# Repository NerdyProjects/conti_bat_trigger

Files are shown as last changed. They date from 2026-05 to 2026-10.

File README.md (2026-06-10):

## Contiakku Triggerplatine

Die Conti-Akkus aus dem Finger-Forum liegen immer noch rum, eine Platine muss her, damit es einfach wird.

[Foren Thread: Conti-Akku, Technikfaden](https://www.fingers-welt.de/phpBB/viewtopic.php?t=19876)

**Status: Untested**

### Funktionalität
* 4,8mm Flachstecker auf der Platine, die direkt auf den Akkustecker passen (zusätzliches Gehäuse empfehlenswert, da ohne kein Verpolschutz!)
* ESP32-C3 Supermini als Basis: Billig, einfach, mit CAN, USB, Wlan.
* Versorgung vom Akkupack oder Charger
* Trigger des Wakeups auf 12V oder 0V
* Trigger des Wakeups auf 12V für Akkus im Deepsleep, wenn Ladegerät angeschlossen
* Wachhalten per CAN

### Timeline
* Mitte Mai: PCB Bestellung
* Bis Ende Mai: Erste Tests geplant

## Errata
### HW v1 (Prod. 2026-05-06)
 * Fehlender Widerstand am Wakeup-Pullup. Wenn Pullup und Pulldown gleichzeitig aktiviert werden würden, kommt es zum Kurzschluss. Abhilfe: Leiterbahn zwischen D13 und R13 durchtrennen, einen Widerstand 1-5k darüber löten. Der passt gut auf die Pads mit drauf. Alternativ den Trace zwischen R15 und D13 (der von Q3 zu D3 geht) durchtrennen, etwas Lötstopp wegkratzen und dort die 1-3k einlöten.
 * Spannungsregler ist immer an - der Conti-Akku gibt auch im Aus-Zustand etwas Spannung am Batterie-Pin aus. Das reicht um die Platine "halb" zu starten - der ESP hat keinen Strom, aber die LED leuchtet. Führt zu höherem Ruhestrom bei gesteckter Platine.

 ### HW v2 (Prod. 2025-05-29)
 * Spannungsregler Enable ist auf etwa 7,5V Einschaltschwelle konfiguriert, allerdings gibt der Akku eine Leerlaufspannung von knapp 16V aus im abgeschalteten Zustand. Leider startet der Spannungsregler dann immernoch, die Platine braucht wenige mA Strom. Damit die Platine sowohl Lade-Wakeup (Versorgung per BAT+) und Entladewakeup (Versorgung über 12Vout) kann, gibt es hier leider keine sinnvolle Einschaltschwelle, ich habe keine Lösung für das Problem.

 ### Aufbau
 #### Charge Only
 * Nur als Ladewachhalter, lädt ?max. 8 Stunden oder bis Akku voll; jedenfalls länger als 1 Stunde?.
 * Achtung: Der Akku stoppt den Ladevorgang scheinbar nicht selbstständig! Überladegefahr!
 
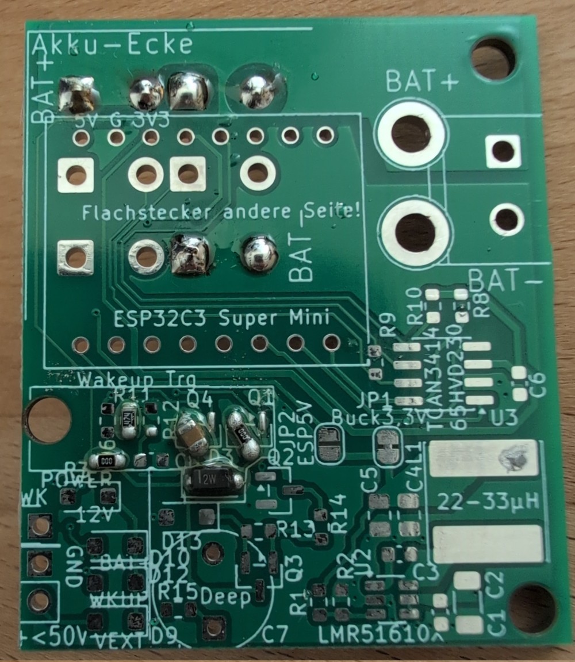
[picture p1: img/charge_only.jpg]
 

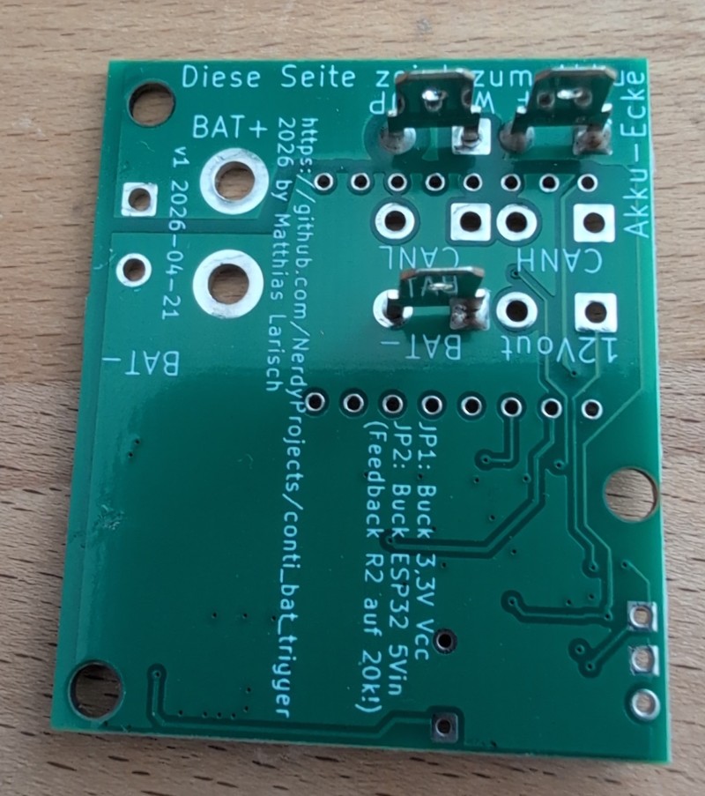
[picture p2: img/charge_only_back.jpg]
 

 Von links nach rechts:
 * R3: 0 Ohm - 1 kOhm
 * R11: 470 kOhm zum Entladen vom Wakeup-Kurzschluss-Trigger-Kondensator
 * Q4 diagonal: 1-10µF Wakeup-Kurzschluss-Trigger-Kondensator
 * D3: 12V Zenerdiode, Strich nach links (Durchlassrichtung rechts nach links)
 * Q1: Brücke von Pin 2 nach 3

 #### ESP Bestückung

 Ganz wichtig: Reihenfolge beachten, sonst kommt man nicht mehr an die Pads dran.

 1. Stiftleisten auf Platine löten - ggf. zum richtigen Abstand halten den ESP bzw. die Adapterplatine schon oben auflegen
 2. Flachstecker bestücken (siehe unten)
 3. Sofern der Display-Adapter zum Einsatz kommt, nun die oberen Stiftleisten hier anlöten - ovale Pads. Achtung: Die obere Reihe kollidiert sehr schnell mit den Flachsteckern, kurze Seite der Stiftleiste nach unten bzw. nachkürzen!
 4. Display Adapter auf Platine löten, dabei nochmal genau mit allen Abständen schauen, ggf. etwas hoch stehen lassen, wenn Flachstecker zu weit hochschauen.
 5. ESP auf Displayadapter bzw. Platine löten - genau darauf achten, dass unterhalb kein Kurzschluss entsteht - ggf. etwas mehr Abstand lassen.

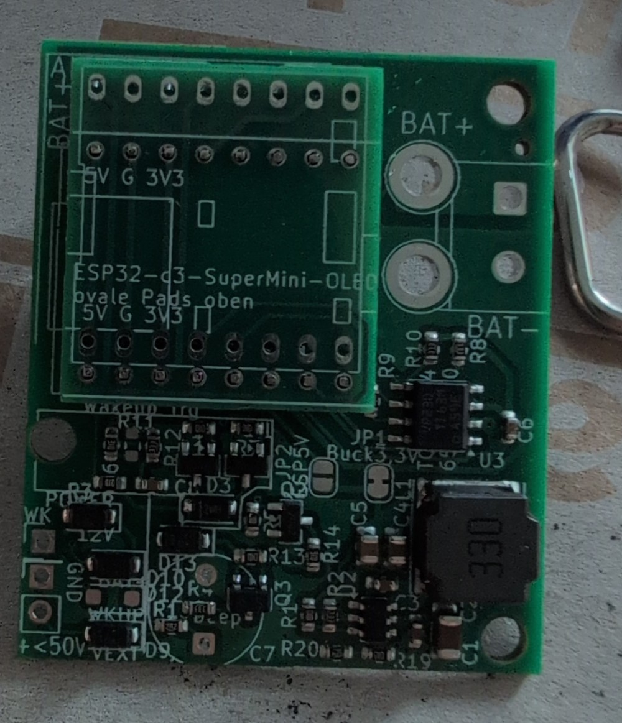
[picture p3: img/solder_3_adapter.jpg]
 

So sieht das aus, wenn man in der falschen Reihenfolge lötet. Mit etwas mehr Abstand noch rettbar :-)

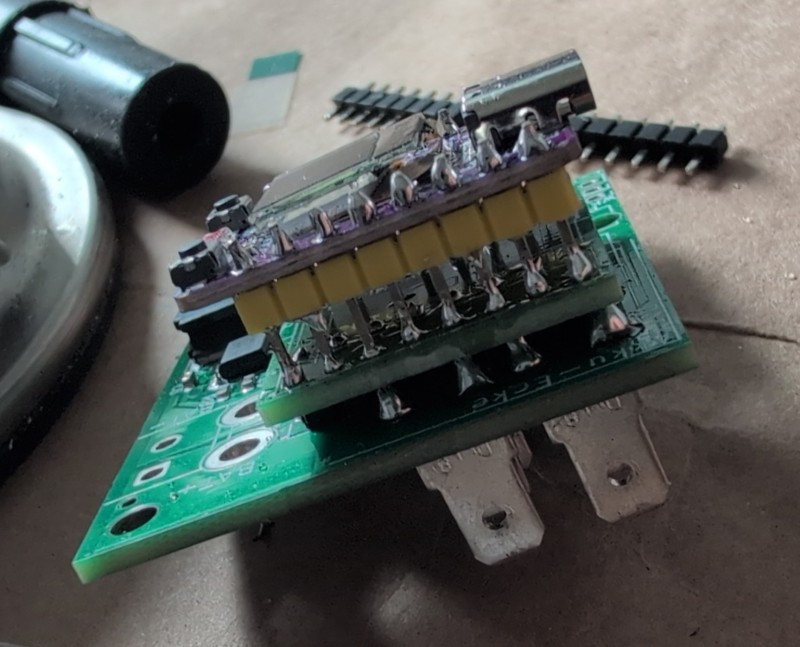
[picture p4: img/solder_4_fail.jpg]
 

Und fertig, mit Oled und der ersten Software:

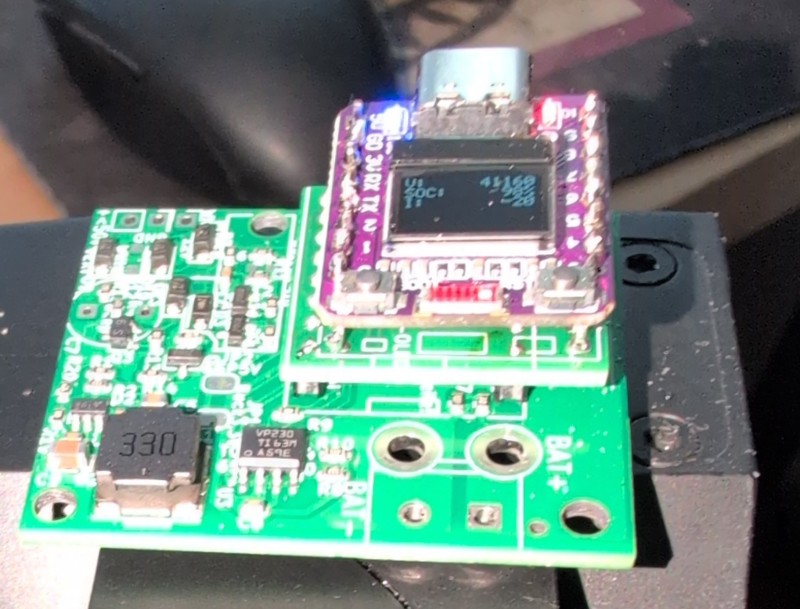
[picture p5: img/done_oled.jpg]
 

 #### Flachstecker-Bestückung

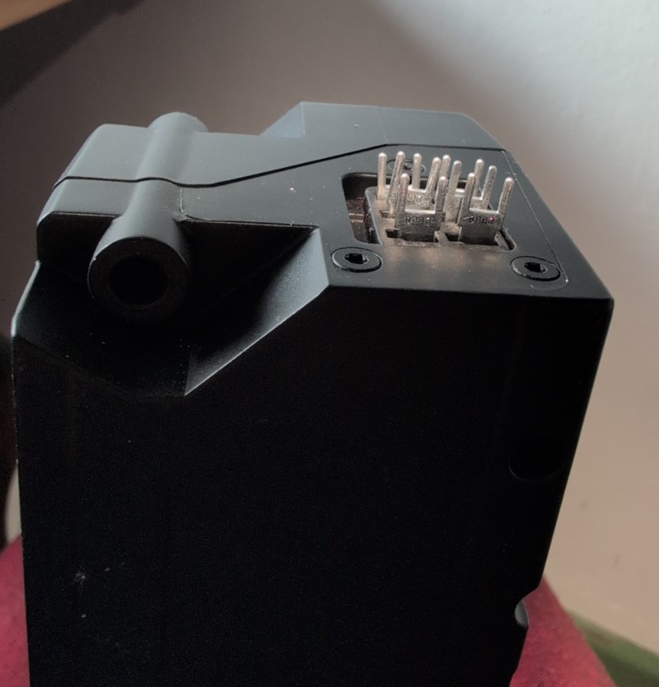
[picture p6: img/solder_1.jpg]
 

 * Flachstecker am besten in einen Conti-Akku stecken. Soweit bekannt, passiert hier bei Kurzschlüssen nichts.

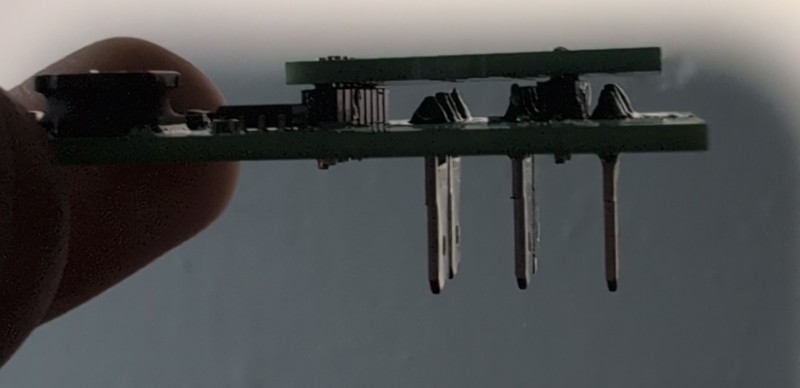
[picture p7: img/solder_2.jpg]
 

 * Beim Anlöten der Platine darauf achten, die Flachstecker nicht ganz durchzustecken, alternativ muss später oben Abstand gehalten werden. Sprich: Insgesamt darauf achten, dass die Flachstecker am Ende keinen Kurzschluss mit der Platine darüber machen.

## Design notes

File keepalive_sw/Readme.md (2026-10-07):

### Keepalive Software

Diese Software kann mit der Hardware den Akku so steuern, dass er im Lade- (Wakeup auf 12V) oder Entlade-(CAN Nachrichten regelmäßig senden) Modus aktiv bleibt.

Hardware: ESP32 C3 SuperMini oder die OLED Variante - in der sdkconfig bzw. per menuconfig gibt es dafür den Abschnitt:
```
#
# Hardware Variant
#
# CONFIG_HW_VARIANT_SUPERMINI is not set
CONFIG_HW_VARIANT_OLED=y
# end of Hardware Variant
```

Die SW macht einen WiFi-AP mit einer Debug-Webschnittstelle auf. Die Zugangsdaten können unter wifi_ap.h konfiguriert werden.

### Display-Akku aktualisieren (ein Befehl)

```bash
python3 tools/stm_display_fw.py flash data/stm32f105_bms_control.bin
```

Wartet auf das Gerät, holt die laufende Applikation per Software-Reset
automatisch in den Bootloader, flasht die Applikationsregion und wartet dann
20 s auf die Applikation. Diese startet **nicht** von selbst: der Abschluss
`0x3E 0x80` loest ohne weitere Rahmen gar keinen Reset aus und ein
Software-Reset fuehrt per Firmware-Logik wieder in den Bootloader — daher nach
dem Flashen Akku/Display kurz stromlos machen (Stecker ab- und wieder
anstecken, Pin-Reset). Nachgewiesen mit `tools/emu.py finishtimer` bzw.
`bootdecision`, Details in `tools/PROTOCOL.md` §9.7.
Optionen: `--wait <Sekunden>` (Standard 120), `--region app|all`,
`--no-reset` (nicht selbst springen), `-q` (weniger Ausgabe).

Voraussetzungen: Python 3 mit `hidapi`, Schreibrechte auf `/dev/hidraw*`
(udev-Regel: `tools/99-continental-ebike.rules`), Akku/Display eingeschaltet.

Hinweise für den Fall, dass es nicht klappt:

* `python3 tools/stm_display_fw.py info` — ist Gerät/Bootloader sichtbar?
* `python3 tools/stm_display_fw.py crc` — stimmt die Applikations-CRC?
  (zerstörungsfrei; Status `0` = stimmt, `1` = verändert/leer)
* Auch wenn das Flashen abbricht, bleibt das Gerät benutzbar: der Bootloader
  liegt unterhalb `0x08008000` und ist **nicht** beschreibbar; das Gerät bleibt
  im Bootloader-Modus erreichbar und kann einfach erneut geflasht werden.
* Details zur Analyse: `data/Flash_WRP_Befund.md`, `tools/PROTOCOL.md`.

### Display-Akku per BLE auslesen (POC)

Das Display (BLE-Name `CEBS`) meldet die BMS-Telemetrie. Kleines POC-Werkzeug
`tools/cebs_ble.py` (Voraussetzung: `pip install bleak`):

```bash
python3 tools/cebs_ble.py              # sucht 'CEBS', verbindet, gibt 1x/s aus
python3 tools/cebs_ble.py --json       # eine JSON-Zeile je Messwert
python3 tools/cebs_ble.py --list       # GATT-Baum anzeigen
```

Erster Continental-Vendor-Service (`00000a00-…`) / erste Charakteristik
(`00000a01-…`) = Verkettung der BMS-CAN-Rahmen `0x404`+`0x405`+`0x406`:
Byte 1–2 = Strom (`int16` LE, mA), Byte 3–4 = Spannung (`uint16` LE, mV),
Byte 5 = SOC (%), Byte 6 = SOH (%, Vermutung), Byte 7–8 = RemainingCapacity
(mAh), Byte 9–10 = FullChargeCapacity (mAh), Byte 15–16 = **Durchschnittsstrom**
(`int16` LE, mA). Details siehe Modul-Docstring.

Zwei Ströme: `0x404` liefert den schnell nachgeführten Wert, `0x406` (Byte
15–16) einen trägen Durchschnitt (Zeitkonstante ca. 10–20 s, Auflösung
10 mA). Nachgewiesen mit einem ~100-mA-Lastsprung: der erste Wert springt
sofort, der zweite läuft exponentiell nach.

Für eigene Messreihen (z. B. Sprungantworten) gibt es
`tools/cebs_ble_trace.py` – liest mit einstellbarer Rate und schreibt jede
Änderung mit Zeitstempel in eine CSV:

```bash
.venv/bin/python tools/cebs_ble_trace.py --seconds 120 --csv trace.csv
```

Hinweis: Die Charakteristik ist **read-only** (keine Notifications, BlueZ
meldet „Operation is not supported"). Werte müssen also gelesen werden; das
Display aktualisiert sie ca. 1x/s. Nur **eine** BLE-Zentrale gleichzeitig:
Solange ein Rechner verbunden ist, sendet das Display nicht mehr und ist für
andere (z. B. die Handy-App) unsichtbar – Verbindung vorher trennen
(`bluetoothctl disconnect <adresse>`).

### Akku-Check als Android-App

Dieselben Daten als Handy-App für einen schnellen Akkucheck:
`android/CebsBatteryCheck`. Verbindet beim Start automatisch (Scan nach Name
`CEBS`), zeigt Ladezustand/Spannung/Strom/Leistung/Kapazität groß an und
liest ausschließlich – es wird nie etwas geschrieben.

```bash
cd android/CebsBatteryCheck
./gradlew :app:assembleDebug     # oder :app:installDebug mit angeschlossenem Gerät
```

Details: `android/CebsBatteryCheck/README.md`.

### Display-Akku als CAN-Interface nutzen (USB-HID)

Die Display-App ist über ihre normale USB-HID-Schnittstelle
(`Continental eBike System`) auch eine kleine **CAN-Bruecke**: Frames senden
und die von der App gemeldeten Frames mitlesen. Ein Frame ist genau ein
64-Byte-HID-Report; Details (Adressen, Filter, Sequenz) stehen in
`tools/PROTOCOL.md` §10.

```bash
python3 tools/can_hid.py info
python3 tools/can_hid.py send 0x201 01 02 03 04        # einen CAN-Frame senden
python3 tools/can_hid.py send 0x201 01 02 --repeat 10  # zyklisch senden
python3 tools/can_hid.py batch --frame "0x201 01 02" --frame "0x202 03 04"
python3 tools/can_hid.py listen 5                      # CAN-Frames mitlesen
```

* **Senden** geht fuer jede 11-Bit-ID **ausser `0x550`** (die Firmware
  filtert an `0x0801D522` fehlerhaft); Nutzlast <= 8 Byte. `0x550` ist der
  reine App-Nachrichtenkanal.
* **Mitlesen** liefert bei Original-Firmware nur die fest verdrahteten IDs
  `0x422 0x425 0x101 0x331 0x668`. Fuer **generischen Empfang** (jedes Frame)
  die Firmware mit dem optionalen Patch C1 bauen und flashen:
  ```bash
  python3 tools/patch_bms.py --can-sniffer        # P1..P7 + C1, CRC neu
  python3 tools/stm_display_fw.py flash data/stm32f105_bms_control.bin
  ```
  C1 haelt den App-Handler-Dispatch erhalten (Details: `tools/PROTOCOL.md` §11).
* Offline pruefen (ohne Hardware): `python3 tools/emu.py canbridge` und
  `python3 tools/can_hid.py selftest`.

### Flash-Inhalt prüfen (verify) und auslesen (dump)

```bash
python3 tools/stm_display_fw.py verify data/stm32f105_bms_control.bin
python3 tools/stm_display_fw.py dump rec
# exakter Beweis -- SCHREIBT 2 KiB in den Flash (verlangt -y):
python3 tools/stm_display_fw.py verify data/stm32f105_bms_control.bin --deep -y
```

* `verify` (**nur lesend**) prüft erst die Datei (CRC-Wort gegen berechnete
  CRC) und dann den Flash über `0x31/0x10202`. Der Bootloader meldet nur ein
  Statusbit (`0` = CRC stimmt, `1` = stimmt nicht). Das belegt die
  **Selbstkonsistenz** des Bereichs: Inhalt und gespeichertes CRC-Wort passen
  zueinander. Ein *anderes*, in sich stimmiges Image würde hier ebenfalls „0"
  ergeben.
* `verify --deep -y` beweist dagegen, dass es **genau dieses** Image ist:
  die letzte 2-KiB-Seite `0x0803F800` (enthält das CRC-Wort) wird gelöscht und
  aus dem Image neu geschrieben, danach wird die CRC abgefragt. Ergebnis `0`
  heißt: der gesamte Applikationsbereich entspricht dem Image.
  **Achtung, das schreibt**: der alte Inhalt dieser Seite ist nicht lesbar
  (der Bootloader kann nur `0x08007800` lesen) und damit auch nicht sicherbar.
  Ohne `-y` verweigert das Tool den Befehl und erklärt die Folgen. Bei einem
  Abbruch nach dem Löschen startet die Applikation nicht mehr — das Gerät
  bleibt dann im Bootloader und wird einfach neu geflasht (der Bootloader
  selbst liegt unter `0x08008000` und ist gesperrt).
* `dump rec` liest den 6-Byte-Record bei `0x08007800` (Kommando `0x22`
  mit Magic `0xF15B`, auf USB kommen 6 Byte zurück; im Original leer).
* **Einen kompletten Dump gibt es nicht**: der Bootloader hat keinen
  Lese-Befehl (10 Kommandos, alle schreiben/steuern; Antworten tragen nur
  Status). Die Record-Seite bei `0x08007800` ist die einzige auslesbare
  Flash-Adresse. Inhaltskontrolle erfolgt daher über `verify`.

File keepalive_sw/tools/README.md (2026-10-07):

# CEBS / Continental Display – BMS-Patch (STM32F105)

Stand: 2026-10-04

Werkzeugpaket zum **Patchen und Flashen** der Display-Firmware über den
USB-HID-Bootloader. Kein SWD/JTAG, kein Löten, kein Windows-Originaltool.

Ergebnis des Patches: Das Display sendet die CAN-Botschaft `0x555`
(BMS-Freigabe) genau dann mit **1**, wenn es läuft – dauerhaft, auch ohne
`0x201`-Keepalive. Details: `docs/BMS_Patch.md`.

## Inhalt

| Pfad | Inhalt |
|---|---|
| `firmware/stm32f105_conti.{bin,hex}` | **Original-Firmware** (unverändert, Ausgangspunkt) |
| `tools/patch_bms.py` | Patches P1…P7 anwenden + Applikations-CRC neu rechnen |
| `tools/o2_cave.s`, `tools/o2_cave.ld` | Assemblerquelle/Platzierung des O2-Patches (Code-Cave) |
| `tools/stm_display_fw.py` | Flash-Werkzeug (USB-HID): flashen, prüfen, diagnostizieren |
| `tools/emu.py` | Emulator (Unicorn): Patch- und Flash-Weg **ohne Hardware** nachvollziehen |
| `tools/cebs_ble.py` | POC: BMS-Telemetrie (Strom/Spannung/SOC/Kapazität) per BLE auslesen |
| `tools/can_hid.py` | CAN über USB-HID der App: Frames senden und mitlesen (siehe `PROTOCOL.md` §10) |
| `tools/patch_bms.py --can-sniffer` | optionaler Patch C1: **generischer** CAN-Empfang, alle Frames ans HID (`PROTOCOL.md` §11) |
| `tools/PROTOCOL.md` | Protokolldokumentation (Bootloader, Kommandos, Fallstricke) |
| `tools/99-continental-ebike.rules` | udev-Regel für USB-Zugriff ohne `root` (Linux) |
| `docs/` | Hintergrund: Patchliste, Firmware-Update-Analyse |
| `patch.sh`, `flash.sh` | Kurzbefehle für die beiden Schritte |
| `esp32/keepalive_sw_supermini.bin`, `esp32/keepalive_sw_oled.bin` | ESP32-C3 App-Images je Hardware-Variante (Web-OTA) |
| `esp32/bootloader.bin`, `esp32/partition-table.bin`, `esp32/ota_data_initial.bin` | ESP32-C3 Bestandteile für den USB-Flash |
| `flash_ota.py` | ESP32 per WiFi/Web-OTA aktualisieren |
| `flash_esp32_usb.sh` | ESP32 per USB flashen (esptool) |
| `idf_env.sh` | Hilfsbibliothek: ESP-IDF-Umgebung finden (von den ESP-Skripten genutzt) |

## 0. Kurzfassung - vorgefertigtes Teil flashen
```bash
sudo apt install python3-venv
python3 -m venv .venv
source .venv/bin/activate
pip install -r requirements.txt
sudo sh tools/install-udev.sh        # kopiert die udev-Regel und lädt sie neu
# Akku per Micro-USB anstecken. Achtung: danach muss der nächste Befehl innerhalb von 5 Sekunden ausgeführt werden, da
# der Akku sich sonst resettet. Passiert das, Kabel für 10 Sekunden abziehen & wieder anstecken.
# Schauen ob alles geht:
python3 tools/stm_display_fw.py info
# Flashen: (ggf. wieder Akku neu anstecken)
python3 tools/stm_display_fw.py flash firmware/stm32f105_bms_control.bin
```

USB Kabel ab, Akku sollte dann über langen (>2s aber <30s) Tastendruck ein- und auszuschalten sein. Er bleibt dauerhaft an, wenn er nicht manuell ausgeschaltet wird.

## 1. Einrichten (einmalig)

```bash
sudo apt install python3-venv gcc-arm-none-eabi binutils-arm-none-eabi

cd cebs_display_bms_patch
python3 -m venv .venv
source .venv/bin/activate
pip install -r requirements.txt
```

**USB-Zugriff ohne `root`** (Linux, einmalig):

```bash
sudo sh tools/install-udev.sh        # kopiert die udev-Regel und lädt sie neu
# danach das Display einmal ab- und wieder anstecken
```

Kontrolle, ob das Gerät sichtbar ist:

```bash
python3 tools/stm_display_fw.py info
```

## 2. Firmware patchen

```bash
./patch.sh
```

Das entspricht:

```bash
python3 tools/patch_bms.py -i firmware/stm32f105_conti.hex \
                           -o firmware/stm32f105_bms_control
```

Ergebnis: `firmware/stm32f105_bms_control.bin` und `.hex`. Die Ausgabe listet
für jeden Patch `angewendet` (P5 ist durch P7 abgelöst und wird automatisch
ausgelassen) und zeigt danach die neue Applikations-CRC.

* nur ansehen, nichts schreiben: `python3 tools/patch_bms.py --list`
* Cave-Code anzeigen (assembliert + Disassembly): `python3 tools/patch_bms.py --print-o2`

## 3. Flashen

1. **USB-Kabel anstecken**, Akku/Display versorgt. Die Anwendung darf laufen –
   das Werkzeug holt sie selbst per Software-Reset in den Bootloader.
2. Flashen:

```bash
./flash.sh
```

Das entspricht:

```bash
python3 tools/stm_display_fw.py flash firmware/stm32f105_bms_control.bin
```

Ablauf (dauert etwa eine Minute):

```
[flash] Applikation laeuft -> Software-Reset in den Bootloader ...
[flash] Bootloader bereit: /dev/hidrawX
[upload] loesche 0x08008000..0x0803ffff   (112 Seiten, Status 0, ~7 s)
[stream] 229376 Bytes = 1+4095 Rahmen a 56 Byte        (Fortschritt, ~20 s)
[stream] Endquittung 0x76 -- Schreibzeiger steht exakt auf 0x08040000.
[upload] App-CRC stimmt (Status 0) -- Bereich vollstaendig und konsistent.
[upload] Sitzung beendet (0x3E 0x80) -- die Applikation startet davon nicht:
         0x3E 0x80 ist KEIN Reset, sondern armt nur einen Zaehler (5000, der
         eigene Rahmen zaehlt schon mit -> 4999), den der Bootloader um eins je
         WEITEREM empfangenen USB-Rahmen verringert (kein Zeitgeber). Danach
         senden wir nichts mehr -- es passiert also nichts, auch kein Reset in
         "dmesg" (tools/emu.py finishtimer). Und selbst ein Reset dort waere
         ein Software-Reset und fuehrt per Firmware-Logik wieder in den
         Bootloader (RCC_CSR.SFTRSTF, tools/emu.py bootdecision).
         -> Akku/Display kurz stromlos machen (Stecker ziehen und wieder
            anstecken) -- nur dieser Pin-Reset startet die Applikation.
[flash] Flash fertig: Image geschrieben und App-CRC (Status 0) bestaetigt.
[flash] Kein Auto-Reset in die Applikation (siehe Reset-Meldung oben, PROTOCOL.md 9.7).
[flash] -> Jetzt Akku/Display kurz stromlos machen (USB-Stecker abziehen und
[flash]    wieder anstecken). Ich warte bis zu 20 s darauf ...
[flash] fertig -- Applikation laeuft.
```

**Wichtig – Power-Cycle nach dem Flashen:** Nach dem Upload macht der
Bootloader von sich aus **keinen** Reset (auch nichts in `dmesg`): `0x3E 0x80`
armt nur einen Zähler, der um *eins je weiterem empfangenen USB-Rahmen* sinkt –
danach kommt kein Rahmen mehr. Und selbst dieser Reset (Software-Reset) führt
per Firmware-Logik *wieder in den Bootloader*, nicht in die Applikation.
Deshalb nach dem Flashen den Stecker kurz abziehen und wieder anstecken
(Pin-Reset) — erst das startet die Applikation. Beides mit dem echten
Bootloader-Code nachgewiesen: `python3 tools/emu.py finishtimer` und
`python3 tools/emu.py bootdecision` (siehe `PROTOCOL.md` §9.7). Das Werkzeug
sagt das nach dem Upload und wartet 20 s auf die Applikation.

Geht etwas schief, wird **kein** Reset ausgelöst – das Gerät bleibt im
Bootloader und kann sofort erneut geflasht werden.

## 4. Wenn es klemmt

| Meldung / Symptom | Ursache und Abhilfe |
|---|---|
| `kein Geraet gefunden` | Kabel/Port wechseln, Versorgung prüfen; udev-Regel installiert? `python3 tools/stm_display_fw.py info` |
| `Bootloader konnte nicht aktiviert werden` | Die App antwortet nicht auf den Reset-Trigger → Gerät stromlos machen, dann erneut `./flash.sh` (Bootloader bleibt aktiv, solange die App-CRC nicht stimmt) |
| `Sitzung liess sich nicht starten (0x10)` | Das Gerät hängt noch im Datenstrom des vorigen Laufs → ~10 s warten (eigener Timeout) oder Strom trennen |
| Werkzeug bleibt direkt nach dem ersten `-> … \| 36 01 …` stehen (keine weitere Ausgabe) | Lese-Timeout 0 blockierte in der klassischen hidapi-Bindung (z. B. Wheel `hidapi 0.15.0`) → aktuelle `tools/stm_display_fw.py` verwenden (`PROTOCOL.md` §9.3.1) |
| `App-CRC stimmt nicht` am Ende des Stroms | Rahmen verloren → erneut flashen, bei Wiederholung langsamer: `--stream-pace-ms 15` |
| `mehr als 40x USB-Handle neu geoeffnet` | USB-Störung (Hub/Kabel) → anderes Kabel/Port, direkt am Rechner |
| `Loeschen fehlgeschlagen (Status 1)` | Flash-Controller ist verriegelt (nach einem Fehlversuch) → **Strom trennen**, kurz warten, erneut flashen |
| App startet nach dem Flash nicht / **kein Reset in `dmesg`** | **Normal:** `0x3E 0x80` macht ohne weitere Rahmen gar keinen Reset (Zähler sinkt nur je Rahmen), und ein Software-Reset kehrt in den Bootloader zurück (`PROTOCOL.md` §9.7) → Stecker kurz abziehen und wieder anstecken (Pin-Reset) |
| `Applikation (noch) nicht sichtbar` nach dem Flash | dito: Power-Cycle ausführen; der Flash selbst war erfolgreich (App-CRC Status 0) |
| App startet auch nach dem Power-Cycle nicht | CRC prüfen: `python3 tools/stm_display_fw.py verify firmware/stm32f105_bms_control.bin` (ohne Hardware: `--offline`); bei Status 1 erneut flashen |

Einzelne Zeilen `[usb] Geraet haengt weiter am Bus -- Knoten neu oeffnen ...`
sind normal: Bei Flash-Befehlen schaltet die Firmware den Systemtakt um, der
USB-Takt fällt kurz weg. Das Werkzeug fängt das ab.

## 5. Prüfen ohne Hardware

```bash
python3 tools/emu.py uploadtool     # kompletter Flashweg gegen echten Bootloader-Code
python3 tools/emu.py blsticky       # Fehlerzustand nach Doppelbeschreiben
python3 tools/emu.py blreadback     # Lese-/CRC-Befehl
python3 tools/emu.py bmspatch       # Patch-Wirkung im Emulator
```

`uploadtool` muss am Ende `Flash == Image` (0 abweichende Bytes),
Schreibzeiger `0x08040000`, App-CRC Status 0 und sauberes `FLASH_SR` melden.

## Technische Kurzfassung (für den Fall der Fälle)

* Applikation: `0x08008000`–`0x0803FFFF`, Applikations-CRC (STM32-Poly) bei
  `0x0803FFFC` über `0x08008000`–`0x0803FFFB`.
* Übertragen wird der Bereich als **Datenstrom**: ein Kommandorahmen `0x36`,
  danach 4095 reine Datenrahmen à 56 Byte; der Bootloader quittiert erst, wenn
  der Schreibzeiger exakt `0x08040000` erreicht (`0x76`).
* Rahmenlängen müssen **gerade** sein (die Firmware programmiert Halbwörter).
* Der Bootloader-Bereich `< 0x08007800` ist nicht über `0x36` beschreibbar.

## 6. BLE-Telemetrie lesen (POC)

Das Display meldet per Bluetooth Low Energy unter dem Namen **`CEBS`** die
BMS-Telemetrie. Kleines POC-Werkzeug: `tools/cebs_ble.py` (Voraussetzung
`bleak`, siehe `requirements.txt`).

```bash
source .venv/bin/activate
python3 tools/cebs_ble.py                 # sucht 'CEBS', verbindet, gibt 1x/s aus
python3 tools/cebs_ble.py --interval 0.5  # 2x/s
python3 tools/cebs_ble.py --json          # eine JSON-Zeile je Messwert
python3 tools/cebs_ble.py --list          # GATT-Baum anzeigen (nichts lesen)
```

Das Werkzeug nimmt den **ersten Continental-Vendor-Service**
(`00000a00-006c-6174-6e65-6e69746e6f43`; der 96-Bit-Teil ist rückwärts
"Continental") und darin die **erste Charakteristik** `00000a01-…`. Diese
20 Byte sind die Verkettung der drei BMS-CAN-Rahmen `0x404`+`0x405`+`0x406`:

| Byte | Typ | Bedeutung | Quelle |
|---|---|---|---|
| 1..2 | `int16` LE | Strom aktuell [mA] | 0x404 b0-1 |
| 3..4 | `uint16` LE | Spannung [mV] | 0x404 b2-3 |
| 5 | `uint8` | Ladezustand SOC [%] (`0xFF` = ungültig) | 0x404 b4 |
| 6 | `uint8` | SOH [%] (Vermutung, konstant 100) | 0x404 b5 |
| 7..8 | `uint16` LE | RemainingCapacity [mAh] | 0x405 b0-1 |
| 9..10 | `uint16` LE | FullChargeCapacity [mAh] | 0x405 b2-3 |
| 11..14 | – | unbekannt (0x405 b4-7) | 0x405 |
| 15..16 | `int16` LE | Strom Durchschnitt (träge) [mA] | 0x406 b0-1 |
| 17..20 | – | unbekannt (0x406 b2-5) | 0x406 |

Die Zuordnung wurde aus der STM-Firmware rekonstruiert (USART-Nachricht
Index 1) und gegen die CAN-Mitschnitte `data/can_log*.csv` geprüft.

**Zwei Ströme:** Das BMS schickt den Strom zweimal – in `0x404` den schnell
nachgeführten Wert und in `0x406` einen trägen Durchschnitt. Nachgewiesen mit
einem Lastsprung (ca. 100 mA): der Wert aus `0x404` springt in derselben
Sekunde, der aus `0x406` läuft exponentiell nach (Zeitkonstante grob
10–20 s, Auflösung 10 mA). Beide stecken in derselben BLE-Charakteristik
(Byte 1..2 und 15..16) – für Restlaufzeit-Schätzungen ist der Durchschnitt
die stabilere Basis.

Beispielausgabe:

```
09:07:38.608 I=  -90 mA  U= 40.710 V  SOC= 89%  SOH=100%  Rem=14010 mAh  Full=15810 mAh   | a6 ff 06 9f 59 64 ...
```

**Nicht** in dieser Charakteristik: Temperatur, Zyklen, Flags (eine
Raumtemperatur von 19,5 °C ließ sich in keinem Feld wiederfinden). Die
Temperatur steckt z. B. in der 5-Byte-Charakteristik `00000a08` (Byte 0
war `0x14` = 20 °C).

Die BLE-Adresse ist eine Zufallsadresse und kann sich nach jedem Neustart
ändern → Standard ist Scannen über den Namen. Mit `--address`, `--service`
und `--char` lässt sich alles fest vorgeben.

## 7. ESP32-C3 Keepalive-Firmware (`keepalive_sw`)

Zusätzlich liegen die Firmware-Images des ESP32-C3-Controllers im Paket – je
Hardware-Variante eines (`supermini` und `oled`). Die Firmware hält den Akku
per CAN-Keepalive wach und öffnet einen WiFi-Zugangspunkt mit
Debug-Weboberfläche (`http://192.168.4.1`). Zugangsdaten:
SSID **`AkkuController`**, Passwort **`akku1234`**.

### 7.1 Web-OTA-Update (empfohlen)

Rechner mit dem AP `AkkuController` verbinden und das passende Image hochladen:

```bash
./flash_ota.py                  # SuperMini (Standard)
./flash_ota.py --variant oled   # OLED-Variante
./flash_ota.py --wait 120       # bis zu 2 min auf das Gerät warten
./flash_ota.py --bin esp32/keepalive_sw_oled.bin
```

Das Skript lädt an `/update` hoch, wartet auf den automatischen Neustart und
prüft über `/api/status`, dass die neue Firmware läuft. Alternativ geht das
im Browser über `http://192.168.4.1/update`.

### 7.2 USB-Flash (Erstinbetriebnahme / Recovery)

Komplett ohne Werkzeug geht es nicht: Der ESP32-C3 hat zwar einen
USB-Bootloader im ROM, er spricht aber das esptool-Protokoll. Für Updates im
laufenden Betrieb ist Web-OTA (7.1) der bequemere Weg.

```bash
./flash_esp32_usb.sh                              # /dev/ttyACM0, SuperMini
./flash_esp32_usb.sh /dev/ttyACM0 --variant oled  # OLED-Variante
./flash_esp32_usb.sh /dev/ttyUSB0 115200
```

Voraussetzung ist `esptool` (aus einer aktivierten ESP-IDF-Umgebung oder im
`PATH`; `ESPTOOL` kann es explizit vorgeben). Geflasht werden Bootloader
(`0x0`), Partitionstabelle (`0x8000`), OTA-Daten (`0xd000`) und Applikation
(`0x10000`); die Bootloader-/Partitionsteile sind für beide Varianten gleich.

### 7.3 Firmware selbst bauen

```bash
tools/build_esp32.sh                  # beide Varianten -> build_supermini/, build_oled/
tools/build_esp32.sh --variant oled   # nur eine Variante (supermini|oled)
```

Die Variante steckt in `CONFIG_HW_VARIANT_{SUPERMINI,OLED}`. Das Skript legt
je Variante eine eigene `sdkconfig` im Build-Verzeichnis an (Basis ist die
Projekt-`sdkconfig`); die Projekt-`sdkconfig` selbst bleibt unangetastet.
Ergebnis u.a. `build_<variante>/keepalive_sw.bin` – genau dieses Image
erwartet `flash_ota.py`. Das komplette Release-Paket bauen:

```bash
tools/build_dist.sh            # alles, inkl. beide ESP32-Varianten
tools/build_dist.sh --no-esp   # nur STM32-Teil, kein ESP-IDF nötig
```

Die ESP-IDF-Umgebung wird entweder aus `IDF_PATH`/`IDF_PYTHON_ENV_PATH`
übernommen oder automatisch aus `~/.espressif/tools/activate_idf_v*.sh`
(EIM) geladen.

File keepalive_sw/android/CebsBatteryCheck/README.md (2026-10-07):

# Akku-Check (Android)

Minimale Android-App, die per BLE den Akkustatus des CEBS-Displays ausliest und
für einen schnellen Akkucheck übersichtlich darstellt. Gegenstück zu
`tools/cebs_ble.py`, nur als Ein-Tipp-App fürs Handy.

* Verbindet **beim Start automatisch** (BLE-Scan nach Name `CEBS`) und
  verbindet nach Abbruch selbstständig neu.
* Zeigt Ladezustand (groß, farbig), Spannung, Strom (momentan), Strom Ø, die
  geschätzte **Restdauer**, Leistung, Rest- und Vollkapazität, SOH sowie die
  Rohbytes der Charakteristik.
* Liest **ausschließlich**. Es wird nie etwas geschrieben – der Akku bleibt
  unangetastet.
* Gibt die Verbindung **frei, sobald die App in den Hintergrund geht**
  (Home-Taste, Bildschirm aus) und verbindet beim Zurückkommen neu. Das ist
  nötig, weil das Display nur eine BLE-Zentrale annimmt und dann auch keine
  Werbung mehr sendet – sonst käme kein anderes Gerät mehr heran.

## Datenquelle

Erster Service auf der Continental-Basis-UUID
`00000a00-006c-6174-6e65-6e69746e6f43` und darin die Charakteristik `0x0a01`
(ersatzweise die erste lesbare). Die 20 Byte sind die Verkettung der
BMS-CAN-Rahmen `0x404` + `0x405` + `0x406`:

| Byte | Typ | Bedeutung |
|---|---|---|
| 1..2 | `int16` LE | Strom [mA] (reagiert schnell) |
| 3..4 | `uint16` LE | Spannung [mV] |
| 5 | `uint8` | SOC [%] (`0xFF` = ungültig) |
| 6 | `uint8` | SOH [%] |
| 7..8 | `uint16` LE | RemainingCapacity [mAh] |
| 9..10 | `uint16` LE | FullChargeCapacity [mAh] |
| 11..14 | – | unbekannt |
| 15..16 | `int16` LE | Strom Ø [mA] (Durchschnitt, träge) |
| 17..20 | – | unbekannt |

Verkabelung/Dokumentation: `keepalive_sw/tools/README.md` Abschnitt 6.

### Zwei Ströme und Restdauer

Das BMS liefert den Strom zweimal: Byte 1–2 ist der schnell nachgeführte Wert
(CAN `0x404`), Byte 15–16 ein träger Durchschnitt (CAN `0x406`). Messung mit
einem ~100-mA-Lastsprung: der erste Wert springt innerhalb einer Sekunde, der
zweite läuft exponentiell nach (Zeitkonstante grob 10–20 s, Auflösung 10 mA).

* **Restdauer** = Restkapazität / Entladestrom, gerechnet mit dem
  *Durchschnittsstrom* – der ist dafür die stabilere Basis. Angezeigt als
  `X h Y min`, ab 100 h in Tagen (`5 Tage 18 h`); beim Laden steht dort `lädt`,
  in Ruhe `–`.
* Das Vorzeichen steht für die Richtung: negativ = entladen, positiv = laden.
  Die Richtung gilt als „Ruhe", solange |I| < 30 mA ist – dann gibt es auch
  keine Restdauer.

**Vorzeichen des Stroms:** negativ = Entladen, positiv = Laden. Das ist eine
Annahme aus dem POC-Mitschnitt (`I = -90 mA` bei SOC 89 %) und wurde durch
Lastsprünge bestätigt (Last → Strom wird negativer).

Die Charakteristik ist **read-only** – Notifications lehnt das Gerät ab. Die
App liest deshalb im Sekundentakt (das Display aktualisiert seine Werte selbst
nur etwa 1x/s).

## Bauen und installieren

Voraussetzungen: JDK 17, Android SDK (`local.properties` mit `sdk.dir=…`),
Netzwerkzugriff für den Gradle-Wrapper.

```bash
cd keepalive_sw/android/CebsBatteryCheck
./gradlew :app:assembleDebug            # baut app/build/outputs/apk/debug/app-debug.apk
./gradlew :app:installDebug             # per adb aufs angeschlossene Gerät
./gradlew :app:testDebugUnitTest        # Tests der Byte-Dekodierung
```

Alternativ das Verzeichnis in Android Studio öffnen und dort starten.

## Berechtigungen

* ab Android 12: `BLUETOOTH_SCAN` (mit `neverForLocation`) und `BLUETOOTH_CONNECT`
* bis Android 11: `ACCESS_FINE_LOCATION` (BLE-Scan-Vorgabe des Systems)

Die App fragt diese beim ersten Start selbst ab.

## Aufbau

| Datei | Inhalt |
|---|---|
| `model/BatteryStatus.kt` | Dekodierung der 20 Byte |
| `ble/BleBatteryClient.kt` | Scan (Name `CEBS`), Verbindung, Notify/Read, Reconnect |
| `ble/BleUiState.kt` | Verbindungszustand + Messwerte für die UI |
| `BatteryViewModel.kt` | hält den Client über Konfigurationswechsel hinweg |
| `MainActivity.kt` | Compose-Oberfläche |

Hinweis: Die BLE-Adresse des Displays ist eine Zufallsadresse und wechselt nach
jedem Neustart – deshalb wird immer über den Namen gesucht.

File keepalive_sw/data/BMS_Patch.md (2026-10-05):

# BMS-Kontroll-Patch – STM32F105 "Display" (Continental / CEBS)

Ziel: **Das BMS (CAN `0x555` = „Spannung an") folgt deterministisch dem Display.**

| Display-Zustand | STM-Zustandsmaschine | `0x555` | BMS |
|---|---|---|---|
| läuft (2 s Button → ein) | Zustand 2 | `01` | **ein** |
| aus (langer Button → aus) | Zustand 1 / 3 | `00` | **aus** |

Erzeugt von `tools/patch_bms.py` aus `data/stm32f105_conti.hex`.

---

## 1. Warum das BMS bisher nicht zuverlässig einschaltete

`0x555` wird **nicht** ereignisgesteuert gesendet, sondern steht als periodische
TX-Botschaft (ca. alle 100 ms, DLC 1) in der Descriptor-Tabelle; **Bit 0 des
32-Bit-Worts bei `0x2000096C`** ist der Wert. Im Mitschnitt `can_log-3.csv` sieht
man das deutlich: alle ~100 ms ein `0x555`-Frame, anfangs `00`, ab t ≈ 1,9 s `01`.

Es genügt also, den Pufferinhalt zu setzen. Der Sender `0x0801673C` tat das aber
nur, wenn **drei** Bedingungen gleichzeitig erfüllt waren:

```c
void f_1673C(void) {                     // wird zyklisch in Zustand 2 gerufen
    if ([0x2000087E] != 1) {             // (1) Flag nur bei Empfang von CAN 0x201
        set_0x555(0);                    //     -> setzt 0x555 aktiv auf 0!
        return;
    }
    if (ramp == 15) set_0x555(1);        // (2) Rampenzähler muss exakt 15,
    ...                                  //     20, 30 oder 60 treffen
}
```

Dazu kam: `0x08016822` ist die Zustandsmaschine (läuft, wenn `f_1FD8E() != 0`):

| Zustand | Ablauf |
|---|---|
| 0 (Boot) | `f_b59c() == 2`? → 2, sonst → 1 |
| 1 | `f_166b0()` (ADC-Bypass + 500-ms-Zähler); bei Modus 2 → Zustand 2 |
| 2 | **`f_1673C()` (0x555-Logik)**; bei Modus 4 → Zustand 1 + `f_167B6()` |
| 2 | **`f_f1a0()==1` oder `[0x200008FF]==1` → Zustand 3 + `f_167B6()` + Standby** |
| 3 | nur `f_167da()` – **wird nie wieder verlassen** (Endzustand bis Power-Cycle) |

Die Abschaltpfade führen also in einen **Endzustand**, der BMS *und* Display
kostet – ohne Reset kommt man nicht heraus.

**Fazit:** `0x555` hing an CAN `0x201`, an einem Rampenzähler und an einem
Zustandsautomaten mit einer Sackgasse. Deshalb war das Einschalten unzuverlässig.

---

## 2. Bewertung des vorhandenen Patches

`data/edited_stm32f105_always_on_display.hex` enthält genau **3 geänderte Bytes**
gegenüber dem Original:

| Adresse | Original | Geändert | Wirkung |
|---|---|---|---|
| `0x08001A34` | `01` | `00` | Bootloader: App-CRC-Prüfung ausgehebelt |
| `0x080167AE` | `00` | `01` | `f_1673C`: Zweig „`[0x87E] != 1`" setzt `0x555 = **1**` statt `0` |
| `0x080167BE` | `00` | `01` | `f_167B6`: **Abschaltpfad setzt `0x555 = 1` statt `0`** |

Bewertung:

* Der Ansatz greift an der richtigen Stelle an (`0x555`-Puffer), ist aber
  **unvollständig**: er hebt nur die Abfrage `[0x2000087E] != 1` aus. Die
  Rampenbedingung (Punkt 2 oben) bleibt bestehen — `0x555` wird erst gesetzt,
  wenn der Rampenzähler 15 erreicht. Und die Zustandsmaschine kann weiterhin in
  den Endzustand 3 laufen, was `0x555` wieder auf 0 zieht.
* `0x080167BE` (Abschaltpfad) wurde **mitgepatcht** – dadurch geht das BMS bei
  ausgeschaltetem Display **nie mehr aus**. Das ist genau das Gegenteil des
  gewünschten Verhaltens.
* Die App-CRC in `0x0803FFFC` wurde **nicht** neu berechnet
  (`edited…hex`: CRC `0xca61f91b`, gespeichert `0x561feb04`). Das fällt nur
  nicht auf, weil die Prüfung in `0x08001A34` zugleich abgeschaltet wurde.

Kurz: als Notlösung brauchbar, aber er hängt weiterhin an den Zufälligkeiten der
Zustandsmaschine und kann das BMS nicht mehr abschalten.

---

## 3. Der Patch

`data/stm32f105_bms_control.bin` / `.hex` – erzeugt mit
`python3 tools/patch_bms.py`. Nur **17 Bytes** weichen vom Original ab
(8 + 2 + 2 + 1 Codebytes + 4 CRC).

### P1 – `0x0801673E` (8 Byte): `0x555 = 1`, sobald Zustand 2 läuft

```asm
;                  vorher                              nachher
0x0801673C: b510  push {r4, lr}                  b510  push {r4, lr}
0x0801673E: 4b76  ldr  r0, [pc, #180]  \         2001  movs r0, #1
0x08016740: 7800  ldrb r0, [r0, #0]     | 0x87E  f7fc fb6e  bl 0x8012E20   ; set_0x555(1)
0x08016742: 2801  cmp  r0, #1           |        bf00  nop
0x08016744: d133  bne.n 0x80167AE      /          ...   (Rampe läuft weiter)
```

`f_1673C` wird **nur** in Zustand 2 aufgerufen → `0x555 = 1` ist damit direkt an
„Display läuft" gekoppelt. Die 0x201-Abhängigkeit *und* die Rampenverzögerung
entfallen. Der folgende Rampen-Code bleibt unverändert erhalten (er setzt
denselben Wert und schreibt weiterhin `[0x20000727]`), damit sich sonst nichts
ändert.

Kosten: `f_1A616` wird jetzt zyklisch mit „1" gerufen statt mit „0" — exakt
dieselbe Aufruffrequenz wie im Original-Zweig `set_0x555(0)`.

### P2 – `0x080167BE` (1 Byte): Abschaltpfad schaltet das BMS wieder aus

`f_167B6` (Zustand 2 → 1 bzw. 2 → 3) schreibt `0x555 = 0`. Originalwert
wiederhergestellt; damit gilt: **Display aus → BMS aus.**

### P3 – `0x08001A34` (1 Byte): CRC-Prüfung des Bootloaders bleibt aktiv

`movs r5, #1` im CRC-Vergleich (`0x08001A02`). Das Werkzeug rechnet die CRC
korrekt nach (verifiziert gegen das Original: `0x561FEB04`), die Prüfung kann
also bleiben. Vorteil: Ein unvollständig geflashter Block landet im
USB-HID-Bootloader statt in einer halben Applikation.

### P4 – `0x080168A8` (2 Byte): keine Sackgasse mehr

```asm
0x080168A8:  03 d0  beq.n 0x80168B2   →   0a e0  b.n 0x80168C0
```

Überspringt `state = 3` + `0x555 = 0` + Standby. Zustand 2 wird damit **nur
noch** über den Display-Aus-Modus 4 verlassen (Richtung Zustand 1, aus dem es
zurückgeht) — kein Dauer-Aus mehr durch weggelaufene Watchdog-Flags
(`0x200008FF`, `0x20000994` Bit 0).

> Ohne P4 bleibt das ursprüngliche Verhalten erhalten; aufrufen mit
> `python3 tools/patch_bms.py --without P4`.

### P5 – `0x08009492` (2 Byte): Abschalt-Timer ausgebaut

Der zyklische Task `0x080093D2` (Periode 100 Ticks, ~100 ms) enthält einen
Countdown, der den STM selbst abschaltet:

```c
// Abschnitt 0x08009484..0x080094B8
if (f_0F390() <= 10 && mode != 4 && f_0EACA() != 1 && f_20144() != 1) {
    // keine Aktivität erkannt
    if ([0x20000100] != 0) {
        if (--[0x20000100] == 0)
            [0x200008FF] = 1;      // -> Zustand 3 = Dauer-Aus (Standby)
    }
} else {
    [0x20000100] = 3000;           // Nachladen (0xBB8)
}
```

Das ist der einzige firmware-seitige Auto-Abschalt-Countdown, der in
`[0x200008FF]` mündet — dieselbe Flag, die auch die Zustandsmaschine in den
Endzustand 3 treibt. Entfernt wird er durch Umbiegen der Verzweigung:

```asm
0x08009492:  04 d1  bne.n 0x800949E   →   ff e7  b.n 0x8009494
```

Ab jetzt wird der Zähler bei jeder Iteration auf 3000 nachgeladen und kann nie
mehr 0 werden; der Pfad `0x080094B4..0x080094B6` ist damit unerreichbar.
Der Rest des Tasks (Display-Zustandsmaschine, CAN-Status, ADC, LED) bleibt
unverändert.

> **Zeitangabe (nachgerechnet, nicht geschätzt):** Der RTOS-Tick ist
> **1 ms** — `0x0800AB36` schreibt `SysTick_LOAD = 71999` (= 72000 Takte bei
> 72 MHz) und `SysTick_CTRL = 7`. Gegenprobe aus dem CAN-Mitschnitt: die
> 0x1B5-Heartbeats kommen exakt alle **10 ms** (`can_log-3.csv`: 234, 244, 254,
> 264 …), also eine Task mit 10 Ticks.
>
> Damit gilt: Task `0x080093D2` = 100 Ticks = **100 ms Takt**, und
> 3000 × 100 ms = **300 s ≈ 5 Minuten Inaktivität** — **nicht 8 Stunden**.
> Der Countdown ist außerdem **aktivitätsabhängig**: er läuft nur, wenn
> `f_0F390() <= 10 && mode != 4 && f_0EACA() != 1 && f_20144() != 1`.
> **P5 ist also _nicht_ der 8-Stunden-Timer** (siehe Abschnitt 4).
>
> Ohne P5: `python3 tools/patch_bms.py --without P5`.

### P6 – `0x0801B944` (1 Byte): CAN-Bus-Off-Erholung einschalten

```asm
0x0801B942:  orr.w r1, r1, #1    →    orr.w r1, r1, #0x41    ; INRQ | ABOM
```

Siehe Abschnitt 4. Ohne P6: `python3 tools/patch_bms.py --without P6`.

### P7 – `0x080093D8` + Cave `0x0803FF00`: O2-Selbstversorgung

Statt die Schutzlogik abzuschalten, stellt P7 den Zustand her, den die Firmware
bei regelmäßigem Motor-Keepalive hätte: ein Trampolin im 100-ms-Task springt in
eine Code-Cave (28 Byte, im freien Block ab `0x08038184`), die das `0x201`-Latch
`[0x2000087E] = 1` setzt und die Nutzlast `[0x20000A0C] = 0x0100` schreibt
(Wire-Bytes `{00 01}` = „Fahrt"). Danach ruft sie die ersetzte
Zustandsmaschine auf.

```asm
0x080093D8:  0d f0 23 fa   (bl 0x8016822)  →  36 f0 92 fd  (bl 0x0803FF00)
```

Damit meldet die **echte** Formel `f_0F390() = 0x0100/10 = 25 > 10`:

* Der 5-Minuten-Timer lädt nach → **P5 wird überflüssig und automatisch
  übersprungen** (`--without P7` schaltet P5 wieder ein).
* Die Rampe in `f_1673C` findet das Latch gesetzt → `0x555 = 1` (P1 bleibt als
  Absicherung, ist aber nicht mehr nötig).

Quellcode: **`tools/o2_cave.s`** (Platzierung `tools/o2_cave.ld`), Bauen und
Anzeigen mit `python3 tools/patch_bms.py --print-o2`; Details, Bytes und die
Adress-Symbole in Abschnitt 10.

### Was *nicht* gepatcht wurde

Beabsichtigt unverändert: die Rampenlogik, `f_166B0` (ADC-Bypass),
`f_16678` (Init), alle CAN-Filter, der Watchdog selbst und die
BMS-Dialogfunktionen (`0x551`/`0x550`/`0x552`).

---

## 4. Zweite Ursache: der CAN-Controller bleibt stumm (STM läuft weiter)

**Symptom:** keine CAN-Nachrichten mehr (auch keine 0x1B5-Heartbeats), aber die
Batteriestands-LEDs leuchten weiter — der STM ist also nicht abgestürzt.

Das ist in der Firmware klar sichtbar. Der bxCAN des STM32F105 hat einen
Fehlerzähler; überschreitet TEC 255, geht er in den **Bus-Off** und nimmt nicht
mehr am Bus teil. Dort kommt er nur heraus, wenn **`CAN_MCR.ABOM`** gesetzt ist
(dann erholt er sich nach 128×11 rezessiven Bits selbst) *oder* wenn Software
`MCR.INRQ` erst setzt und dann wieder löscht.

Was die Firmware tatsächlich tut:

| Funktion | Verhalten |
|---|---|
| `f_1B8C8` (0x0801B8C8) | liest `CAN_ESR` (über `CAN_MSR+20`) und unterscheidet **Bus-Off** (`\|0x40`), Error-Passive (`\|0x20`), Error-Warning (`\|0x10`), Init (`\|0x02`) |
| Task 0x08009404 | `if (status & 0x72)` → `f_135DE(1)` — der Fehler wird also **nur gemeldet** (0x1B2-Fehlernahmen) |
| `f_1B3D8` (0x0801B3D8) | CAN-Modus setzen: SLEEP löschen, Mailboxen abbrechen, `MCR \|= 1` (INRQ), auf INAK warten |
| `f_1B93C` (0x0801B93C) | dieselbe Sequenz — **der einzige Ort, an dem `MCR` beschrieben wird** |
| `f_1C398` (0x0801C398) | CAN-Zustandsmaschine: Zustand 2 = INIT, Zustand 3 = RUNNING; Re-Init nur, wenn `[0x20000AF9] == 2` |

Damit gilt:

* `CAN_MCR` wird **ausschließlich** mit `\|=1` (INRQ) und `&=~2` (SLEEP)
  beschrieben → **`ABOM` (Bit 6) ist nie gesetzt**.
* `CAN_ESR` wird gelesen, der Zustand aber nur als 0x1B2 gemeldet — es gibt
  **keine automatische Reaktion** auf Bus-Off im Normalbetrieb.
* Die Re-Init-Kette (`[0x20000AF9] = 2` → `f_1C320`) wird nur aus dem
  Init-Pfad heraus aufgerufen, nicht aus dem Fehlerpfad `f_1C362`
  (der setzt nur `[0x20000AFA] = 4`).

**Wie es ohne eigene 0x555-Frames dazu kommt — ACK-Fehler:**

Ein Bus-Off braucht **keine** Kollision. Es genügt, dass der STM zeitweise der
**einzige aktive Knoten** am Bus ist — also z. B.:

* der ESP ist aus / im Reset, oder
* der ESP hat seinen Transceiver über den **STANDBY-Pin** (GPIO21) stillgelegt,
  oder
* der Bus ist nicht (korrekt) abgeschlossen bzw. eine Leitung unterbrochen.

Dann wird das **ACK-Bit** im ACK-Slot von niemandem dominant gezogen. Der bxCAN
wertet das als Fehler, sendet ein Error-Frame und erhöht **TEC um 8** pro
Vorgang. `MCR.NART` ist **nicht** gesetzt, es wird also automatisch wiederholt —
nach spätestens 32 Fehlversuchen steht TEC über 255 und der Controller geht in
**Bus-Off**. Das passiert bei reinem Senden, ganz ohne Fremdverkehr.

**Ergebnis:** Ein einziger Bus-Off lässt die Firmware dauerhaft stumm, während
Display, LEDs und Aufgaben weiterlaufen — genau das beobachtete Bild.
**P6 setzt `MCR.ABOM`**; der Controller holt sich dann nach 128×11 rezessiven
Bits selbst zurück, sobald wieder ein zweiter Knoten am Bus ist.

### Weitere Abschaltquellen (geprüft)

| Quelle | Ort | Wirkung |
|---|---|---|
| Countdown `[0x20000100]` | 0x080094B4 | `[0x200008FF] = 1` → Zustand 3 — **mit P5 entfernt** |
| 0x201-Watchdog-Timeout | 0x080195D8 | `[0x200008FF] = 1`, wenn Zustand 4 und Flag gesetzt — **mit P4 entschärft** |
| CAN-ID 0x300 | 0x0801D11E | `[0x200008FF] = 1` — **nicht erreichbar**, 0x300 fehlt in der RX-Filterliste 0x08036CD8 |
| `[0x20000994]` Bit 0 | 0x0800F1A0 | Zustand 2 → 3 — **mit P4 entschärft** |

Der RTOS-Tick ist **1 ms** (`SysTick_LOAD = 71999` in `0x0800AB36`, bestätigt
durch 10-ms-Heartbeats im Mitschnitt). Ein 8-Stunden-Wert ist im gesamten Flash
**nicht vorhanden**. Geprüft wurden — jeweils als Literalpool-Eintrag *mit*
Code-Referenz, als `movw`-Immediate und als Rohbytefolge in allen vier
Ausrichtungen:

`28800`, `288000`, `2880000`, `28800000`, `480`, `2880`, `14400`, `21600`,
`43200`, `86400`, `172800`, `57600` — **null Treffer**.

Die einzigen großen Zeitkonstanten im Image sind `36000000` (0x080132A4, wird
per `udiv` als Teiler benutzt — Zeitbasis-/Frequenzrechnung, kein Timer) und
`71999` (SysTick-Reload). Die 8 Stunden kommen daher **nicht** aus einem
Konstanten-Vergleich dieser Firmware.

Was in Frage kommt:

* ein **Akkumulator** aus vielen Reloads (dann müsste ein Zähler saturieren) —
  Kandidat: `[0x20000904]` in `0x080169BA`, saturiert bei `0x071C71C7`
  (= 2³²/36 ≈ 119,3 Mio.). Das ist aber eine **Statistik** (Trip-/Maximalwert,
  geht per `f_0EFC2(8, …)` nach außen) und **setzt kein Abschaltflag**;
* eine Abschaltung von außen (BMS, Motorsteuergerät, LED-Board) über CAN —
  beachte: `[0x200008FF] = 1` wird auch von **CAN-ID 0x300** (`f_1D114`)
  ausgelöst (in der Original-Filterliste nicht enthalten, aber ein anderes
  Gerät könnte 0x555/0x554-seitig abschalten);
* ein Hardware-Timer außerhalb des STM.

---

## 5. Sicherheit der Patches

* **Keine Stack-Änderung.** P1 nutzt nur `r0` innerhalb der vorhandenen
  `push {r4, lr}` / `pop {r4, pc}`-Klammer. P4 ist ein reiner Sprung.
* **Keine Literal-Pools überschrieben.** Der Pool bei `0x080167F4` wird von
  P1 nicht berührt; P1 endet vor `0x08016746`.
* **Keine neuen Sprungziele.** P1 nutzt den vorhandenen Aufruf `0x08012E20`,
  P4 springt auf das vorhandene `0x080168C0`.
* **Rücksprung bleibt erhalten.** Nach P1 läuft der Rest von `f_1673C`
  unverändert bis `pop {r4, pc}`.
* **Idempotent & selbstprüfend.** `patch_bms.py` prüft an jeder Stelle die
  erwarteten Ausgangsbytes und bricht bei fremder Firmware ab; ein zweiter Lauf
  liefert bitidentisch dasselbe Image.
* **CRC-Nachrechnung** mit der verifizierten STM32-Hardware-CRC
  (`crc32_stm32`), Ergebnis `0x5ED6678E` – geprüft mit
  `tools/stm_display_fw.py verify`.

---

## 6. Verifikation

### Statisch

* **Byte-Diff:** genau **46 Bytes** geändert – P1 (8) + P4 (2) + P6 (1) +
  P7 (Trampolin 3 + Code-Cave 28) + CRC (4). P5 entfällt (durch P7 abgelöst).
* **Disassembly** aller Stellen mit `arm-none-eabi-objdump` geprüft:
  Sprungziele lösen exakt auf (`bl 0x8012e20`, `b.n 0x80168c0`,
  `orr.w r1, r1, #0x41`, `bl 0x803ff00`) — letzteres kommt direkt aus dem
  Assembler-Build von `tools/o2_cave.s`.
* **CRC:** `0x81517823`, geprüft mit `tools/stm_display_fw.py verify`.
* **HEX/BIN-Roundtrip** bitidentisch; Skript bei zweitem Lauf idempotent.

### In der Emulation (`tools/emu.py bmspatch`)

37 Checks gegen **Original und gepatchte Firmware gleichzeitig**; die gepatchte
wird absichtlich über den `.hex`-Pfad geladen. Es läuft jeweils echter
Firmware-Code (Unicorn/Cortex-M3), keine Nachbildung:

| # | Prüfung | Original | Patch |
|---|---|---|---|
| A | `0x201`-Handler `0x080167E4` setzt `[0x2000087E]` | 1 | 1 |
| B | `f_1673C` ohne `0x201` (Rampe 0 / 15) | 0 / 0 | – |
| C | `f_1673C` mit `0x201` (Rampe 0 / 15) | 0 / **1** | – |
| D | `f_1673C` ohne `0x201` (Rampe 0) | – | **1** |
| E | Abschaltpfad `f_167B6` | – | **0** |
| F | Zustandsmaschine, Modus 2 → Zustand / `0x555` | 2 / 1 | 2 / 1 |
| G | Zustand 2 + `[0x8FF]=1` + `f_f1a0()=1` | **3 / 0** | **2 / 1** |
| I | Modus 4 (Display aus) → Zustand / `0x555` | – | 1 / 0 |
| J | Bootloader-CRC `0x08000924` == Wert bei `0x0803FFFC` | OK | OK |
| K | Task mit leerer Nutzlast **ohne** Cave-Lauf (Harness) | Flag **1** | Flag **1** |
| L | `f_1B93C` → `CAN_MCR` | `0x01` | `0x41` (ABOM) |
| M | echte Formel `f_0F390()` bei Nutzlast `0x0000` / `0x0100` | 0 / 25 | 0 / 25 |
| M | Abschaltflag dazu | **1** / 0 | **1** / 0 |
| N | **P7-Cave im Image ohne P1/P5**: Latch, Nutzlast, Zustand, `f_0F390()`, Timer, Flag | – | 1 / `0x0100` / 2 / 25 / **3000** / **0** |
| N | Gegenprobe gleiches Image **ohne** Cave | – | Timer 0, Flag **1** |

Aussage der Schlüsselpaare:

* **B vs. C** — die Emulation ist originalgetreu: das Original *kann* `0x555`
  auf 1 setzen, aber **nur** mit empfangenem `0x201` *und* Rampenzähler 15.
  Das ist genau die Ursache des unzuverlässigen Einschaltens.
* **D** — der Patch hebt beide Bedingungen auf.
* **G vs. H** — beweist P4: im Original führt `[0x200008FF]` in die Sackgasse
  Zustand 3 (dauerhaft aus, auch für das Display), mit Patch bleibt Zustand 2.
* **J** — die emulierte CRC-Funktion rechnet über den echten Applikationsbereich
  und trifft den gespeicherten Wert → der Bootloader startet das gepatchte Image
  (P3 ist also unschädlich).
* **K** — der Task `0x080093D2` läuft mit realem Code eine Iteration durch; im
  Original setzt der abgelaufene Countdown `[0x200008FF] = 1`, mit P5 bleibt das
  Flag 0 und der Zähler steht auf 3000.
* **L** — `f_1B93C` schreibt im Original nur `MCR = 0x01`, mit P6 `0x41`
  (INRQ | ABOM).

Regression: alle 15 Emulator-Szenarien laufen unverändert durch
(`crc`, `dispatch`, `frame`, `setaddr`, `writeblk`, `appreset`, `trigger`,
`blprobe`, `blsession`, `nmstate`, `msgprobe`, `hidtrigger`, `caninject`,
`uploadtool`, `bmspatch`).

---

## 7. Flashen

```sh
python3 tools/patch_bms.py                              # erzeugt bin + hex
python3 tools/stm_display_fw.py verify data/stm32f105_bms_control.hex
python3 tools/stm_display_fw.py upload data/stm32f105_bms_control.bin --region app
```

`--region app` schreibt `0x08008000..0x0803FFFF`. Der Bootloader-Bereich
(`0x08000000..0x08007FFF`, enthält P3) bleibt davon unberührt und muss getrennt
geschrieben werden (`--region all` bzw. separater `setaddr`-Lauf), falls die
CRC-Prüfung im Bootloader wieder aktiviert werden soll.

## 8. Erwartetes Verhalten danach

| Ereignis | Erwartung |
|---|---|
| 2 s Button → Display ein | Zustand 0 → 2, `0x555 = 01` innerhalb ~100 ms, BMS ein |
| langer Button → Display aus | Modus 4 → Zustand 1, `0x555 = 00`, BMS aus |
| Button → wieder ein | Modus 2 → Zustand 2, `0x555 = 01`, BMS ein |
| ESP-Keepalive `0x201` fällt aus | `0x555` **bleibt 1** (P1); kein Dauer-Aus mehr (P4) |
| Bus-Off am ESP | Display und BMS bleiben an |
| Bus-Off am **STM** | P6: der bxCAN erholt sich nach 128×11 rezessiven Bits selbst — Heartbeats laufen wieder an |
| Inaktivität (Display an, kein Verkehr) | **P7**: Aktivität ist dauerhaft vorhanden (`f_0F390() = 25`), der Zähler lädt nach — kein Abschalten nach 5 min |
| Gar kein CAN am Bus (kein ESP, kein Motor) | **P7**: `0x555 = 01` trotzdem, Display bleibt an |

Kontrolle im Web-UI (`/canlog`): Spalte `0x555` muss dem Displayzustand folgen,
und `0x1B5` Byte 0 sollte `0x19` statt `0x00` zeigen.

---

## 9. Ganz ohne externe CAN-Nachrichten: wo `0x201` wirklich gebraucht wird

Frage: Reicht der Patchsatz, damit die Firmware **ohne jede** externe Botschaft
(kein `0x201`, kein Motor-Keepalive) eigenständig aktiv bleibt — oder braucht sie
den Zustand „`0x201` mit Fahrt" weiterhin?

### 9.1 Was `0x201` im Datenmodell ist (verifiziert)

| Fakt | Wert |
|---|---|
| ID → Signal | `0x201` = Signal **14** (Tabelle `0x08036BE4`) |
| Signal → RAM-Slot | **`0x20000A0C`**, erwartete Länge **4** (`0x08036C80[14]`, `0x08036C68[14]`) |
| Decode-Handler | `0x08019512`, Post-Call `0x080167E4` |
| Post-Call | setzt **Latch `0x2000087E = 1`** |
| Latch löschen | nur `f_16678`, aufgerufen **einmalig** über `0x080093A6` (Task-Init) → „`0x201` war irgendwann da" |
| zusätzlich | Handler setzt Bit 7 in `0x20000AF7` (Leser: `0x0801C144`) |
| Nutzlast | bleibt als 4 Byte in `0x20000A0C` stehen |

Die **Nutzlast ist das Aktivitätssignal**: `f_19926()` liest die ersten beiden
Bytes von `0x20000A0C` als 16-Bit-Wort (Little-Endian).

### 9.2 Die drei Verbraucher

1. **`0x555`-Freigabe** in `f_1673C`: Gate auf das **Latch** → durch **P1**
   entfernt.
2. **5-Minuten-Timer** (`0x08009480`, siehe P5): lädt nur nach, wenn
   `f_0F390() > 10` mit `f_0F390() = Wort(0x20000A0C) / 10`. Ohne `0x201` ist das
   Wort 0 → `0/10 = 0` → Countdown `3000 × 100 ms = 300 s` → `0x200008FF = 1`
   → Zustand 3 (Dauer-Aus) → `0x555 = 0`.
   Mit dem ESP-Keepalive `{00 01 00 00}` ist das Wort **`0x0100` = 256** →
   `256/10 = 25 > 10` → Aktivität erkannt. **Das ist der „Fahrt"-Zustand, den
   die Firmware ohne CAN nicht sieht.**
   Im Emulator beidseitig nachgewiesen (Checks `M` in `tool/emu.py bmspatch`):
   `P_X201=0x0000 → f_0F390()=0 → Flag=1` und
   `P_X201=0x0100 → f_0F390()=25 → Zähler=3000, Flag=0`.
3. **Abschaltaktion** `f_195BE` (Aktionstabelle `0x08037908` Index 7, nur
   indirekt aufgerufen): wenn **Fahrzustand `0x20000C5C == 4`** und Latch `== 1`
   → löscht `0x20000A0C/0D` **und** setzt `0x200008FF = 1`. Die Wirkung ist
   durch **P4** entschärft, der Schreibzugriff auf die Nutzlast bleibt.

Weitere Aktivitätsquellen im selben Task (für den CAN-losen Fall irrelevant):
`f_B59C() == 4` (USB-/NM-Zustand), `f_EACA() == 1`, `f_20144() == 1`.

### 9.3 Was der heutige Patchsatz leistet — und was er kostet

* Mit **P1 + P4 + P5** ist emulativ kein Pfad mehr offen, der ohne CAN in
  Zustand 3 oder auf `0x555 = 0` führt (Checks `F`, `G`, `K`).
* Es ist aber **Symptombekämpfung**: die Firmware „glaubt" weiterhin, es gebe
  keinen Motor und keine Fahrt. Alles, was an `f_1FD8E()` (Fahrzustand
  `0x20000C5C`, **24 Aufrufer**) oder an `0x20000AF7` hängt, bleibt im
  „Nicht-Fahrt"-Zweig.
* **P5** hebelt die Schutzlogik aus (immer nachladen), statt den Zustand
  herzustellen.

### 9.4 Optionen

| # | Ansatz | Wirkung | Bewertung |
|---|---|---|---|
| **O1** | **Nutzlast vorbelegen**: in `f_16678` (läuft einmal beim Task-Start) `[0x20000A0C] = 0x0100` schreiben, optional Latch `[0x2000087E] = 1` | Die Firmware sieht exakt den Zustand „`0x201` mit Fahrt-Byte liegt an"; der 5-Minuten-Schutz bleibt **echt** und scharf | **bevorzugt**: wenige Bytes, P4/P5 werden überflüssig. Hürde: in `f_16678` ist kein freier Literalpool-Platz — die Adresse `0x20000A0C` muss aus einem vorhandenen Pool erreicht werden (z. B. `0x0801984C` in `f_195BE`) oder der Schreibbefehl zieht in eine andere Init-Funktion |
| **O2** | **Signalquelle nachbilden**: `0x20000A0C` zyklisch (z. B. im 100-ms-Task) neu schreiben | wie O1, aber „lebendig" (auch nachdem `f_195BE` den Slot gelöscht hat) | mittel: ~20 B Code, braucht freien Platz |
| **O3** | `f_0F390` (oder das nur von ihm genutzte `f_19926`) auf konstant > 10 patchen (`movs r0,#11; bx lr`) | Timer lädt immer nach | 2–4 Byte, aber qualitativ dasselbe „Aushebeln" wie P5 |
| **O4** | Statusbit `0x20000AF7` mitbedienen | Firmware meldet BMS/Diagnose „`0x201` gesehen" | offen: Leser `0x0801C144` noch nicht analysiert |
| **O5** | Fahrzustand `0x20000C5C = 4` setzen | Verhalten wie „Fahrt" in allen 24 `f_1FD8E()`-Nutzern | **riskant**: Nebenwirkungen unbekannt; der Writer ist noch nicht lokalisiert (kein Literalpool-Eintrag, vermutlich über Basiszeiger/Struktur) |
| **O6** | nicht patchen, `0x201` weiter vom ESP senden (70–100 ms) | minimal-invasiv | Abhängigkeit bleibt: ESP-Ausfall oder Bus-Off ⇒ Abschaltung nach 5 min |

### 9.5 Empfehlung

1. **O1** umsetzen und danach **P4/P5 entfernen** — das ist die semantische
   Lösung: der Zustand wird hergestellt, statt die Schutzlogik zu lähmen.
   Prüfbar mit den `M`-Checks (müssen unverändert 25/0 liefern, jetzt ohne
   Eingriff am Timer).
2. `f_16678` ist der richtige Ort (läuft genau einmal, schreibt schon
   RAM-Flags); alternativ das Task-Init `0x080093A6`.
3. **O5** erst angehen, wenn der Writer bekannt ist — sonst blind.
4. Offen bleibt die **Batterie-Seite**: die beobachteten „5 Minuten" passen
   exakt zu `3000 × 100 ms` im Display, also stammt der Standby-Schutz aus der
   Display-Firmware. Ob die BMS zusätzlich eine eigene Standby-Regel hat, lässt
   sich nur über einen Mitschnitt (`can_log`) mit `0x555 = 01` über > 5 min
   klären. Solange das nicht belegt ist, ist „BMS-seitiger Timer" Spekulation.

---

## 10. Platz für O2: freier Block und Einhängepunkt

Im Applikationsbereich gibt es einen **zusammenhängenden gelöschten Bereich von
32 376 Byte (31,6 KiB)**:

```
0x08038184 .. 0x0803FFFB   0xFF  (endet direkt vor dem App-CRC-Wort 0x0803FFFC)
```

> **Lehre aus dem ersten Versuch: 0xFF heißt *nicht* „unbenutzt“.** Der Block
> wird an seinem **ersten Byte referenziert** — der Datenbereich enthält einen
> Deskriptor `0x08037F54 -> 0x08038184`. Die Stelle wird also möglicherweise als
> *Wert* gelesen (z. B. als „belegt/frei“-Feld); ein Cave-Start genau dort ist
> riskant. Gegenprobe, dass 0xFF Daten sein können: der 148-Byte-0xFF-Lauf bei
> `0x0802F901` ist in Wahrheit eine **36-Byte-Record-Tabelle**
> (`0x08035AB8..` zeigt auf `0x0802F707`, `+0x24`, `+0x48` …) — dort liegen
> `0xFF`-Bytes als Nutzdaten.
>
> Deshalb prüft `tools/patch_bms.py` jetzt **vor** dem Patchen (und bricht sonst
> ab): Cave-Bereich muss `0xFF` sein **und** kein 4-Byte-Wort im ganzen Image darf
> in die 2-KiB-Seite der Cave zeigen (Pointer, Deskriptoren, Literal-Pools sind
> alle 4-Byte-ausgerichtet). Ausnahme: Zeiger auf das App-CRC-Wort.

**Gewählter Platz: `0x0803FF00`** — in der letzten App-Seite
`0x0803F800..0x0803FFFF`. Sie enthält nur das CRC-Wort bei `0x0803FFFC` und ist
sonst leer; sie ist die einzige Stelle im gelöschten Block, die **kein**
Datensammler belegen darf (er würde die CRC zerstören). Die Seite ist damit
nicht nur „unreferenziert“, sondern strukturell reserviert. Kleinere
0xFF-Lücken (1 KiB bei `0x08023F0D` usw.) sind dagegen **nicht** verwendbar —
sie gehören zu Tabellen (siehe oben).

**Einhängepunkt (Trampolin, ohne ein einziges freies Byte an Ort und Stelle):**
umgesetzt als **P7** in `tools/patch_bms.py`. Statt Code einzuklemmen, wird ein
vorhandener `bl` im 100-ms-Task **umgebogen** und der ursprüngliche Aufruf aus
dem Block heraus nachgeholt:

```asm
; 0x080093D8 im 100-ms-Task 0x080093D2
- bl 0x8016822        ; Zustandsmaschine      (0d f0 23 fa)
+ bl 0x0803FF00      ; -> Code-Cave          (36 f0 92 fd)
```

**Der Code selbst ist Assembler-Quelltext im Repo** — `tools/o2_cave.s`
(Platzierung `tools/o2_cave.ld`, Bauen/Anzeigen mit
`python3 tools/patch_bms.py --print-o2`). `patch_bms.py` assembliert ihn beim
Patchen selbst und prüft die Adressen als Symbole (`--defsym`):

```asm
o2_tramp:                            @ .tramp, platziert auf 0x080093D8
    bl      o2_cave                  @ = 0x0803FF00

o2_cave:                             @ .cave, platziert auf 0x0803FF00
    push    {r4, lr}
    movs    r0, #1
    bl      F_167E4                  @ Latch [0x2000087E] = 1 ("0x201 war da")
    ldr     r1, =O2_X201_SLOT        @ r1 -> 0x20000A0C
    movs    r0, #O2_X201_B0
    strb    r0, [r1, #0]
    movs    r0, #O2_X201_B1          @ 0x01 = "Fahrt"
    strb    r0, [r1, #1]
    bl      F_16822                  @ der ersetzte Originalaufruf
    pop     {r4, pc}
    .ltorg                           @ Literalpool: 0x20000A0C
```

Fertige Bytes (28 + 4, aus dem Assembler):

```
Cave      0x0803FF00: 10 b5 01 20 d6 f7 6e fc 03 49 00 20 08 70 01 20 48 70
                       d6 f7 86 fc 10 bd 0c 0a 00 20
Trampolin 0x080093D8: 36 f0 92 fd        (ersetzt 0d f0 23 fa)
```

> **Gelernt beim Bau (vom Emulator gefunden):** `f_167E4` ist eine normale
> C-Funktion und clobbert nach AAPCS `r0..r3`. Wird der Zielzeiger `r1` **vor**
> dem Aufruf geladen, zeigt er danach auf `0x1` → Schreibzugriff ins Nichts
> (`UC_ERR_MAP` im Emulator). Deshalb wird `r1` erst **nach** dem Latch-Aufruf
> geladen. Die Reihenfolge im `.s` ist damit nicht beliebig.

Wirkung: die Firmware sieht dauerhaft genau den Zustand, den sie bei
regelmäßigem `0x201` mit Fahrt-Byte hätte (`f_0F390() = 25 > 10` → 5-Minuten-Timer
lädt nach). Damit wird **P5 überflüssig** — `patch_bms.py` überspringt P5
automatisch, solange P7 dabei ist (`--without P7` schaltet P5 wieder ein) — und
der Originalcode funktioniert von selbst:

* `f_1673C` (Rampe) findet das Latch gesetzt und setzt `0x555 = 1` beim ersten
  Rampenpunkt (15, ~1,5 s nach Zustandswechsel) — der Wert bleibt danach stehen.
* Der Countdown lädt nach, weil Aktivität erkannt wird.

**P1 bleibt trotzdem drin** (Absicherung, kostet nichts) — P7 allein genügt aber
ebenfalls, das prüft der Emulator mit einem Image ohne P1/P5 (Checks `N`).

**Achtung, dann wird P4 wichtig:** mit dauerhaft gesetztem Latch löst die
Abschaltaktion `f_195BE` (`Fahrzustand 0x20000C5C == 4` **und** Latch) das
Abschaltflag `0x200008FF` aus. Ohne P4 führt das in den Endzustand 3. P4 deckt
genau diesen Pfad ab.

## 11. Verhalten, wenn `0x201` sofort mit „Fahrt" beginnt

Geprüft gegen `f_1673C` (siehe §1) — es gibt **keine** „der Motor muss im Stand
starten"-Sperre:

| Bedingung | Wirkung |
|---|---|
| Latch `0x2000087E == 1` | Voraussetzung für alles Weitere (P1 entfernt sie) |
| Rampenzähler `== 15` | `0x555 = 1` — **ohne** weitere Bedingung |
| Rampenzähler `== 20 / 30 / 60` | `0x555 = 1` nur wenn `f_0F1B2() == 0` |

`f_0F1B2()` ist **Bit 1 des `0x202`-Signals** (Slot `0x20000A04`, DLC 8). Das ist
die einzige Stelle, an der ein Motor-/Fahrzeugzustand die Freigabe beeinflusst —
und sie wirkt nur auf die **Wiederholungspunkte** 20/30/60, nicht auf den ersten
(15). Praktisch heißt das:

* Ja, es gibt ein Gate, und es liest den Motorzustand (`0x202` Byte 0 Bit 1).
  Ob das „Motor läuft" oder „Stillstand erkannt" bedeutet, ist **nicht belegt**
  (kein Wakeup-/Timeout-Nachbar, kein Default-Wert im Image).
* Nein, es verhindert den Start nicht: der erste Freigabepunkt nach dem
  Zustandswechsel ist immer möglich.
* Wichtig für die Fahrt-Erkennung: das „Fahrt"-Byte ist **Byte 1** der
  `0x201`-Nutzlast. `{00 01 ...}` ⇒ Wort `0x0100` ⇒ `f_0F390() = 25 > 10`.
  `{00 00 ...}` (**nur Latch, kein Fahrt-Byte**) ⇒ Wort 0 ⇒ **keine** Aktivität ⇒
  der 5-Minuten-Timer läuft trotz `0x201` ab. Genau deshalb sendet der
  Referenzcode `sendCAN(0x201, 4, 0, 1, 0, 0)`.

## 12. Abschaltung bei zu hohem Strom — STM oder BMS?

Beobachtung: die Batterie schaltet ab, wenn innerhalb von ~2 s nach `0x555 = 1`
ein zu hoher Strom (≈ > 2 A) fließt. Befund aus der STM-Firmware: **das ist
nicht dort implementiert.**

Belege:

1. `set_0x555` (`f_12E20` → `f_1A616`, schreibt **Bit 0** des Worts `0x2000096C`)
   hat genau **6 Aufrufer**, alle in `f_1673C`/`f_167B6`:
   `0x08016750/64/78/8C` (Rampe, `= 1`) und `0x080167B0/0x080167C0` (`= 0`).
   Damit sind die **einzigen** Abschaltgründe: fehlendes Latch oder das
   Verlassen von Zustand 2 (Modus 4, `f_F1A0()`, Abschaltflag). **Kein
   stromabhängiger Pfad.**
2. Die Batteriedaten (`0x404` → Slot `0x200009D0`) haben drei Code-Nutzer:
   `f_0F164` (Byte 4 = SOC, auf 100 begrenzt), `f_0F170` (Byte 5),
   `0x08017B48/0x08017B66` (Byte 4/5 in einen TX-Rahmen) und `f_19864`
   (**Byte 2–3 = Spannung**). **Byte 0/1 (Strom) wird nirgends gelesen.**
   Einziger Schreiber: `f_195A4` setzt Byte 4 auf `0xFF` (Daten ungültig).
3. Der STM misst den Hauptstrom nicht selbst (nur ADC-Kanal 9 für den Taster/
   die Boardspannung, `0x0800E4C2`).
4. Muster: „kleines Zeitfenster nach dem Einschalten + niedrige Stromgrenze" ist
   eine klassische **Vorlade-/Softstart-Prüfung**. Sie sitzt dort, wo der
   Leistungsschalter und der Stromsensor sitzen — in der **BMS**.

**Gegenprobe am Motorrad (entscheidend, ohne Firmware-Eingriff):** während des
Abschaltens den `can_log` mitlaufen lassen.

* Läuft `0x555 = 01` **weiter** (und `0x1B5`-Heartbeats) bis der Bus stirbt →
  die BMS hat abgeschaltet, der STM hat es nicht befohlen.
* Geht `0x555` auf `00` oder brechen die Frames ab, obwohl der STM noch
  Spannung hat → der STM hat abgeschaltet; dann greift einer der drei Pfade aus
  (1). Zusätzlich `0x420` beobachten: **Bit 0** ist der einzige externe
  „Fehler → Endzustand 3"-Eingang (`f_F1A0()`, Slot `0x20000994`). Der ESP32
  sendet `0x420` nicht — solange das so bleibt, kann dieser Pfad nicht feuern.

Was daraus folgt: gegen eine BMS-Vorlade-/Überstromregel hilft kein
STM-Patch. Ansatzpunkte sind dann die Last-Seite (Vorladewiderstand/Relais wie
im Original-Controller, Last erst nach der Freigabe zuschalten) oder ein
späteres `0x555 = 1` (der ESP32 hat dafür bereits den `0x555`-Test-Timer).
Der einzige *firmware*-seitige Hebel wäre, `0x555` erst nach dem Anlaufen der
Last zu setzen — dafür gibt es aber keinen Sensor im STM.

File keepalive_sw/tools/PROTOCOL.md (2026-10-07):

# STM "Display" (STM32F105) – Bootloader / Upload-Protokoll

Alle Adressen beziehen sich auf `data/stm32f105_conti.bin`
(Basis `0x08000000`) bzw. `data/stm32f105_conti.dis`.
Legende: **[V]** = aus dem Disassembly verifiziert, **[R]** = rekonstruiert
(plausibel, aber noch nicht am Gerät bestätigt).

## 1. Flash-Layout
| Bereich | Adresse | Inhalt |
|---|---|---|
| Bootloader | `0x08000000`–`0x08007FFF` | USB-HID-Updater, Vektor-Tabelle, SP=`0x2000B248` |
| Applikation | `0x08008000`–`0x0803FFFB` | Display-App, Vektor-Tabelle `0x08008000`, SP=`0x2000C9E0` |
| CRC32(App) | `0x0803FFFC` | Big-Endian, STM32-HW-CRC (Poly `0x4C11DB7`) |

Verifiziert: `CRC32(0x08008000..0x0803FFFB) = 0x561FEB04`.

## 2. Boot-Entscheidung und Trigger [V]
`0x08001A92`:
```
r4 = (RCC_CSR.Resetquelle == SFTRST) ? 0 : 1      ; 0x080019F0 -> 0x08001B7A
r0 = (CRC32(App) != CRC@0x0803FFFC) ? 1 : 0       ; 0x08001A02 -> 0x08000924 (HW-CRC)
if (r4 == 1 && r0 == 0)  0x08001A3C   # App starten
else                     0x08001AAA   # USB-HID-Bootloader bleiben
```
* `0x08001B7A` liest `RCC_CSR` (`0x40021000+0x24`), Maske `0x50000000`:
  * **SFTRST** gesetzt → Bootloader-Modus (Rueckgabe 1)
  * sonst (POR/PIN/WWDG) → App starten, wenn CRC ok
* Sprung in die App `0x08001A3C`: `MSP = [0x08008000]`, `bx [0x08008004]`.
* `0x08001B66` = `NVIC_SystemReset` (`AIRCR=0x05FA0004`).

### Update-Trigger
1. **Software-Reset** (`NVIC_SystemReset`) → SFTRST → Bootloader-Modus.
   * aus der App heraus: App-Funktion `0x08017FA2`, Aufrufer `0x08016E8E`
     (Arg==2) und `0x08017380` (Arg==1).
   * **ohne App-Mitarbeit:** per SWD `mww 0xE000ED0C 0x05FA0004`
     (SYSRESETREQ) → ebenfalls SFTRST → Bootloader.
2. **App-CRC ungueltig** (unvollstaendiger Flash) → Bootloader bleibt.
3. POR/PIN/WWDG-Reset → App (wenn CRC ok).

## 3. USB
* Produktstrings: Bootloader = **"CEBS Bootloader Mode"**, App =
  **"Continental eBike System"**; Hersteller "Continental",
  Serial "000000000001", Interface-Strings "HID Config"/"HID Interface". **[V]**
* HID: **64-Byte Reports** (IN und OUT). **[V]** (`REPORT_SIZE = 0x40`)
* VID/PID liegen nicht als Konstante im Flash (Deskriptoren werden zur
  Laufzeit in RAM gebaut) → Geraet am besten ueber den **Produktstring**
  finden (macht `stm_display_fw.py`).

## 4. Rahmen (Framing)

Der Bootloader verarbeitet **zwei Kanaele** (`0x2000001C` Byte 1):

**Kanal 1 = USB-HID (verifiziert).** Der 64-Byte-HID-Block landet direkt bei
`0x20000206`; dessen **Byte 0 ist die Laenge**, der Payload folgt ab `+1`.
Ein getrenntes Flag bei `0x20000247` meldet "Report abgeholt" (loescht den
Datenmodus). Buffer-Init/Zeroing: `0x080009D4`, gelesen in `0x08000AC0`.
```
Byte 0   : len                     (Payload-Laenge, 0 = Leer-Report)
Byte 1.. : payload[0..len-1]       payload[0] = Kommando-Code
Rest     : 0x00 bis 64 Byte aufgefuellt
```
**Kanal 2 = gerahmt** (`0x08000AFC`..`0x08000B58`), mit Kopf und fester
20-Byte-Datenphase – vermutlich CAN:
```
Byte 0 : 0x02
Byte 1 : 0x21
Byte 2 : len                       (Payload-Laenge)
Byte 3..: payload[0..len-1]        payload[0] = Kommando-Code
```
**Geraet → Host:** Antwortcode ist immer **`Kommando | 0x40`**, gefolgt von
Laenge/Daten. Beispiel `0x10` → `50 03 01 f4 03 e8`, `0x34` → `74 03 03 80 00`,
`0x37` → `77`, `0x3E|0x00` → `7e 00`. Auf Kanal 2 wird die Antwort in eine
20-Byte-Struktur verpackt und mit Kopf `57 01 20` gesendet (`0x080042AE`).

## 5. Kommandos (Dispatcher `0x08000B5A`, payload[0])
| Code | Handler | Bedeutung |
|---|---|---|
| `0x10` | `0x08000CAC` | **Modus setzen**, Laenge **2**, Arg ∈ {1,2,3,0x81,0x82,0x83} → `[0x20000024]`=Arg; Arg **2/3/0x82/0x83** setzt zusaetzlich `[0x20000028]`=1; ACK `50 <arg> 01 f4 03 e8` **[V]** |
| `0x11` | `0x08000DA2` | Laenge **2**, Arg ∈ {1,3,0x81,0x83} → `[0x20000025]` bzw. `[0x20000026]`=1 **[R]** |
| `0x22` | `0x08000EAE` | Magic in payload[1..2] (Big-Endian), Laenge **3**: `0xF100`→`0x08000EF2` Quittung, `0xF101`→`0x08000E3C` Statusantwort, **`0xF15B`→`0x08000F54` = 6 Byte aus Flash `0x08007800`** (Kanal 2: 8 Byte). Antwort `62 <magic> <6 Datenbytes>`. **Der einzige lesende Befehl.** `0xF15A` liefert Fehler `0x13` (= Schreibmagic von `0x2E`) **[V]** |
| `0x27` | `0x080011DA` | Challenge/Response: Sub `0x11` (Laenge 2) bildet mit `0x08000968` zwei Pruefwerte in `0x2000002C/30` und liefert den ersten als 32-Bit-Wort zurueck (Kanal 1: 6 Byte ab Index 2, Kanal 2: 7 Byte); Sub `0x12` (Laenge 6, payload[1]==1) prueft die Antwort mit `0x080008FE` (`a*i + b*(i+1) == c`, i ∈ 1..5) → 2 Byte Antwort, sonst Fehler `0x35` **[V]** |
| `0x2E` | `0x08001224` | **Geraeterekord schreiben**: Magic **`0xF15A`** in payload[1..2], Laenge **exakt 10** (sonst Fehler `0x13`); Pruefung payload[3] ≤ 99, payload[4] ∈ 1..12, payload[5] ∈ 1..31 (Jahr/Monat/Tag). Loescht 2 KiB bei `0x08007800` (`0x08001964`) und schreibt 8 Byte ab payload[3] (`0x08001998`) — das achte Byte liest der Handler hinter dem Payload aus dem Puffer. ACK `6e f1 5a` **[V]** |
| `0x31` | `0x080013A4` | 24-Bit-Unterkommando aus payload[1..3] (Big-Endian), Laenge ≥ 3: **`0x10202`** = Applikations-CRC pruefen (Laenge 8 und Modus 1, sonst Laenge 4 in Modus 2; verlangt das Flag `[0x20000028]`), **`0x1FF00`** = Flash loeschen (Laenge 13, Adresse payload[5..8], Laenge payload[9..12], je Big-Endian, 2-KiB-ausgerichtet), **`0x10203`** = Quittung (Laenge 4). Alles andere → Fehler `0x12` **[V]** |
| `0x34` | `0x08001514` | **Adresse setzen**: payload[1] Nibbles, payload[3..6] = 32-Bit **Big-Endian**-Adresse → `0x080017BE` **[V]** |
| `0x36` | `0x08001614` | **Block schreiben**: Laenge **2..58**, payload[1]=Sequenz (muss `[0x20000038+0]` entsprechen, sonst Fehler `0x73`), payload[2..]=Daten; `len-2` Bytes werden an `0x20000038+4` programmiert, Zeiger += `len-2`, Sequenz +1 mit **Wrap 255 → 1**; setzt `[0x2000001C]`=1 (Datenmodus) **[V]** |
| `0x37` | `0x080017EC` | **Sequencer-Reset**, Laenge **1** → Seq=1, Zeiger=0; ACK `77` **[V]** |
| `0x3E` | `0x08001884` | **Finish**, Laenge **2**, Arg 0x00 oder 0x80. Arg 0x80 → keine Antwort; **beide Arme armieren nur einen Zaehler** (5000 in `0x20000042`), den der BL um **eins je weiterem empfangenen USB-Rahmen** verringert (`0x08000C04` → `0x0800190A`; **kein** Zeitgeber) und bei 0 `SCB->AIRCR = 0x05FA0004` (`0x08001B66`) schreibt. Ohne Folge-Rahmen passiert also nichts; der Reset fuehrt **nicht** in die Applikation -- siehe 9.7 |
| sonst | `0x08000A46` | Fehler/NAK mit Fehlercode |

Weitere Bausteine **[V]**:
* Schreibzeiger liegt bei `0x20000038+4` (`0x080017BE`).
* Flash-Treiber (nur Bootloader): Unlock `0x45670123`/`0xCDEF89AB` @
  `0x08005314`/`0x0800531C`; WaitForLastOp `0x08005180`; Page-Erase
  `0x080051B4`; Halfword-Programm `0x0800525C`; Wrapper `0x08001964`
  (Erase, Adresse muss 2-KiB-aligned sein) / `0x08001998` (Write).
* Treiber laeuft aus **SRAM** (RAM-Stubs `0x2000B249/63/75/A7/9D/F5` via
  `0x08001004`..`0x08001036`) — noetig, weil STM32F1 nicht aus dem Flash
  lesen kann, waehrend es schreibt.
* Zusaetzlicher Datenstrom-Pfad in der Haupt-Loop `0x08001ACC`:
  Puffer `0x2000025C`, Flush alle **80 Bytes** via `0x0800174E` (fuer
  zusammenhaengende Downloads).

## 6. Per Emulation verifiziert (`tools/emu.py`)
Mit Unicorn (ARM Cortex-M3) werden einzelne Funktionen aus dem Dump mit
präpariertem SRAM/Peripherie aufgerufen:

| Szenario | Ergebnis |
|---|---|
| `crc` | `0x08000924` liefert exakt den Python-CRC → Harness + CRC-Modell OK |
| `dispatch` | Jeder Kommando-Code trifft den erwarteten Handler (alle 10) |
| `frame` | `02 21 <len> <payload>` wird akzeptiert, `len` + Payload korrekt kopiert |
| `setaddr` | `0x34`: Schreibzeiger = BE-Adresse aus payload[3..6] (Payload-Länge **11**) |
| `writeblk` | `0x36`: `len-2` Datenbytes an Zeiger geschrieben, Zeiger += `len-2`, Sequenz +1 |
| `blprobe` | Alle Kommandos mit definierten Laengen → Fehlercodes `0x12/0x13/0x24/0x33/0x73`, ACK `77` bei `0x37` |
| `blreadback` | **Lese-Befehl und CRC-Status**: `0x22` mit `0xF15B` liefert die 6 Byte aus `0x08007800` (mit `0xF15A` keine Daten), Record via `0x2E` schreiben und zuruecklesen, CRC-Status `0`/`1` fuer intaktes/geaendertes Image, `verify` und `verify --deep` (8 bzw. 13 Pruefungen) |
| `blsession` | **Kompletter Upload**: `0x10(3)`→`0x37`→`0x34`→4096×`0x36`→`0x3E`; Zeiger endet exakt auf `0x08040000`, Flash-Inhalt identisch → **OK** |
| `appreset` | `0x08017378(1)` / `0x08016E84(2)` → `AIRCR = 0x05FA0004` |
| `bootdecision` | **Boot-Entscheidung**: `SFTRSTF` (Software-Reset, auch `0x3E 0x80`) → Bootloader; jeder andere Reset → Applikation (jeweils mit/ohne gueltige App-CRC) |
| `finishtimer` | **0x3E-Timer**: `0x3E 0x80` armt Zaehler 5000, der um 1 **je empfangenem Rahmen** sinkt; Reset (`AIRCR`) erst nach ~4999 Folge-Rahmen -- ohne die passiert nichts |
| `trigger` | Dispatcher `0x08018D04` → Reset `0x08017378` (Nachricht-Id `0x304`) |
| `caninject` | CAN-Frame in den echten Empfangshandler `0x0801B066` injizieren |
| `uploadtool` | **Tool-Upload**: `stm_display_fw.Protocol.upload()` gegen `0x08000AAA` — 4100 Reports, 4096 Flash-Writes, Zeiger endet exakt auf `0x08040000`, Inhalt identisch |
| `hidtrigger` | **Tool-Trigger**: `build_app_report()` → App-Empfangspfad → Index 4 → `0x0304` → `0x08017378` (beide Huellen) |
| `bmspatch` | **BMS-Patch**: 19 Checks gegen Original + gepatchte Firmware (aus `.hex` geladen) — 0x555 folgt dem Displayzustand, Abschaltpfad, Zustandsmaschinen-Sackgasse, Bootloader-CRC |

Damit sind Rahmenformat, Kommandocodes, die **komplette Session** und der
Abschluss **bestätigt**.
Aufruf: `python3 tools/emu.py {crc,dispatch,frame,setaddr,writeblk,appreset,bootdecision,finishtimer,trigger,caninject,blprobe,blsession,bmspatch} [-t] [-i <image>]`
`blsession` akzeptiert optional eine Bytezahl (Standard `0x1000`):
`python3 tools/emu.py blsession 0x38000`.

## 7. Flash auslesen (Dump) -- was geht und was nicht

**Ein allgemeiner Dump ist nicht moeglich.** Der Dispatcher `0x08000B5A`
kennt genau zehn Kommandos (Tabelle oben); keines liefert Flash-Inhalt, und
kein Antwortpfad enthaelt Nutzdaten aus dem Speicher -- Antworten tragen
ausser dem Kommandokopf nur Status (der Antwortbau `0x0800130C` leitet nur
Werte aus den Argumenten weiter). Auch die 0x50-Byte-Schreibfunktion
`0x0800174E` und der Puffer `0x2000025C` gehen **ins** Flash, nicht heraus.
Die einzigen Ausnahmen sind:

1. **Geraeterekord (6 Byte)**: Kommando `0x22` mit Magic `0xF15B` liest die
   feste Adresse `0x08007800` (`0x08000F54`, Literal `*(0x08000FE0)`). Die
   Adresse steht als Konstante im Code und ist nicht beeinflussbar; die Seite
   ist im Original leer (`0xFF`) und wird von `0x2E` beschrieben.
2. **CRC-Status (1 Bit)**: Kommando `0x31/0x10202` vergleicht
   CRC32(`0x08008000 + 0x00037FFC`) mit dem Wort bei `0x0803FFFC` und meldet
   **`0 = gleich`, `1 = ungleich`** (Werte des Antwortbaus `0x0800130C`, im
   Emulator bestaetigt -- die fruehere Annahme `1 = ok` war falsch).
   Reichweite und Adresse sind fest verdrahtet; ein Teilbereich ist nicht
   abfragbar.

**Inhalt pruefen statt lesen** (`tools/stm_display_fw.py`):
* `verify <image>` -- **nur lesend** (CRC-Abfrage). Status 0 belegt die
  *Selbstkonsistenz* des Applikationsbereichs (CRC32 passt zum gespeicherten
  CRC-Wort); ein anderes, in sich stimmiges Image liefert ebenfalls 0.
* `verify <image> --deep -y` -- **schreibt** und beweist damit exakt: die letzte
  Seite `0x0803F800..0x0803FFFF` wird geloescht und aus dem Image neu
  geschrieben (setzt das CRC-Wort des Images), danach wird die CRC abgefragt.
  Status 0 ⇔ der **gesamte** Bereich entspricht diesem Image; der alte Inhalt
  der Seite ist nicht lesbar und damit nicht sicherbar. Ohne `-y` bricht das
  Tool mit einer Erklaerung ab, ohne etwas zu senden.
* `dump rec` -- liest den Geraeterekord (`0x22`, 6 Byte). `dump app` erklaert
  die Grenze.

Eine Record-Runde im Emulator (`python3 tools/emu.py blreadback`) zeigt, dass
`0x2E`/`0x22` tatsaechlich schreiben und lesen -- der Rueckkanal ist also ein
**echter** Flash-Zugriff und keine Konstante.

Wichtige RAM-Adressen (aus den Literal-Pools):
* `0x200001CC` = Payload-Puffer, `0x2000001E` = Payload-Länge (halfword)
* `0x20000038` = Flash-State: `+0` Sequenz, `+1/+2` Nibbles, `+4` Schreibzeiger
* `0x20000040` = Erase-State: `+4` Adresse, `+8` Länge (Wrapper `0x08001964`)
* `0x08007800` = Ziel des 2048-Byte-Blocks (Kommando `0x2E`)

### USB-Identitäten (am Gerät verifiziert, Linux-dmesg)
```
idVendor=0x2A8A  idProduct=0x0010  bcdDevice=1.00
Manufacturer: Continental   Product: "Continental eBike System "   Serial: 000000000001
USB HID v1.11 Device   ->   hidraw4
```
Das ist die **App**. Der Bootloader hat denselben Vendor (VID `0x2A8A`) und den
Produktstring **"CEBS Bootloader Mode"** (eigene PID). Das Tool sucht daher
zuverlässig über den Produktstring.

### Trigger aus der App (per Emulation verifiziert)
Der Bootloader betritt den Update-Modus nur bei **SFTRST** (Software-Reset) oder
ungültiger App-CRC. Die App kann also nur per `NVIC_SystemReset` (`0x08017FA2`)
hineinspringen. Verifizierte Pfade (`tools/emu.py`):

```
python3 tools/emu.py appreset   # 0x08017378(1) & 0x08016E84(2) -> AIRCR=0x05FA0004  OK
python3 tools/emu.py trigger    # Dispatcher 0x08018D04 -> Reset 0x08017378         OK
```

* `0x08017378` (Reset wenn Arg==1) und `0x08016E84` (Reset wenn Arg==2)
  schreiben `AIRCR = 0x05FA0004` (SYSRESETREQ). Mit Arg≠Wert passiert nichts.
* Der Event-Dispatcher **`0x08018D04`** erreicht mit gesetztem Nachrichten-State
  den Handler `0x08017378`:
  * `0x20000930` bit6 gesetzt (Event anstehend)
  * Halfword `0x20000928` bit11 gesetzt
  * Byte `0x20000941` = **4** → Tabelle `0x08036F40`, Struktur-Id **`0x304`**
    → `fnarray[3]` (`0x08036F2C`) = `0x08017378` → Reset
  * `0x20000928` Byte0 == 0 und `0x20000942` == 0 (sonst Arg≠1)

Der Trigger ist also eine **proprietäre Nachricht mit Id `0x304`**, kein
standardisierter USB-Request. Nächster Schritt: Producer
von `0x20000928`/`0x20000941` bis zum CAN- oder USB-Eingang zurückverfolgen.

#### Kanal-Analyse (App)
* **CAN**: `IRQ20 (CAN1_RX0)` → `0x0801B066` → `0x0801AFC6` (liest `CAN1_RIR`,
  extrahiert die 11-Bit-ID `(RIR>>21)<<21`, sucht sie in einer Tabelle
  `*(0x0801B30C)` mit bis zu 22 Einträgen, dann Dispatch). CAN-Register
  `0x400064xx` (u. a. `0x4000640C`=RF0R, `0x40006408`=TSR).
* **USB**: `IRQ67 (OTG_FS)` → `0x0800D5F4` (USB-Stack-State `0x20005E40`);
  `IRQ42` → `0x0800D5D3`. (Der Bootloader nutzt `0x50000000` direkt.)
* **Event-/Nachrichtenmodul** `0x08018xxx`: Dispatcher `0x08018D04`, aufgerufen
  von `0x08018E26` (läuft, wenn Byte `0x20000930` != 0, aus `0x08018E38`).
  Tabelle `0x08036F40` (`{min,max,x,id,fn}`), `fnarray` `0x08036F2C`,
  Id `0x304` → `fnarray[3]` = `0x08017378` (Reset).
* **Session-Magics** im Bootloader (Kommando `0x22`, Payload-Länge 3):
  Wire-Bytes `[0x22, 0xF1, 0x00]` = Magic `0xF100` -> Quittung (`0x08000EF2`),
  `[0x22, 0xF1, 0x01]` = Magic `0xF101` -> Statusantwort (`0x08000E3C`),
  `[0x22, 0xF1, 0x5B]` = Magic `0xF15B` -> **6 Byte aus Flash `0x08007800`**
  (`0x08000F54`). Das Schreibmagic `0xF15A` (`0x2E`) liefert hier Fehler `0x13`.
  Achtung: das ist eine andere Baustelle als die Session-Magics der App.
  / `0x08000F54`).

#### Bootloader-Session (per Emulation geloest)
Die frühere Lücke ist geschlossen. Der Schreibpfad wird über `cmd 0x10`
freigeschaltet:
* `0x08001040(r0)` setzt das **"Gueltig"-Flag `[0x20000028]`**; `0x0800120E`
  liest es nur. `cmd 0x34` bricht mit Fehler `0x33` ab, wenn das Flag 0 ist.
* `cmd 0x10` mit Arg 1/0x81 → Flag 0; Arg **2/3/0x82/0x83** → Flag 1.
* `cmd 0x34` setzt die **Schreibfreigabe `[0x20000034]`=1** (`0x08001568`),
  `cmd 0x36` prueft sie (sonst Fehler `0x24`).
* `0x08001998` = `flash_write(ptr, len, buf)`: verweigert `ptr < 0x08007800`
  (Bootloader geschuetzt) und `ptr+len > 0x08040000`.

**Verifizierte Upload-Sequenz** (`tools/emu.py blsession`):
```
0x10 03                    -> 50 03 01 f4 03 e8
0x37                       -> 77
0x34 03 00 <addr BE32> 00… -> 74 03 03 80 00        (Laenge 11)
0x36 <seq> <56 Datenbytes> (x N, seq 1..255 dann wieder 1)
0x3E 80                    (keine Antwort) -> SW-Reset -> App
```
Mit 4096 × 56 Byte (= 0x38000) endet der Zeiger exakt auf `0x08040000`.

Flashen ist ausschließlich über den **USB-HID-Bootloader** möglich (kein
CAN-Update im Dump); CAN/USB sind nur fuer den *Einstieg* in den Bootloader
relevant.

## 7. Offene Punkte (vor dem ersten echten Upload klaeren!)
1. **HID-Report-Wrapper**: Der Emulator verifiziert die Protokollschicht ab
   `0x20000206` (Byte 0 = Laenge). Das Tool sendet daher standardmaessig
   `[len][payload]` (`--wire raw`); mit `--wire hdr` steht die gerahmte
   Variante `02 21 <len> <payload>` bereit. Welche Variante der USB-Stack
   tatsaechlich auf das HID-Out-Report legt, ist ohne Hardware offen.
2. **Trigger-Kanal** (CAN vs USB) der App-Nachricht Id `0x304` sowie deren
   Mehrfachrahmen-Aufbau (0x550/0x552 erreichen als Einzelframe nur die
   BMS-Handler `0x0801C702`/`0x0801CFBC`).
3. **Erase vor dem Schreiben**: `0x08001964` ist ein Erase-Wrapper; im
   Emulator wurde der Flash-Inhalt direkt ueberschrieben. Vor dem echten
   Flashen pruefen, ob `cmd 0x10`/`0x37` das Loeschen ausloest oder ob das
   Tool vorher 0xFF schreiben muss.

Empfehlung fuer die Hardware: einmal mit dem Original-Tool flashen und den
USB-Verkehr mitschneiden (Linux `usbmon`/`tshark`, Windows USBPcap+Wireshark).
Damit ist Punkt 1 sofort geklaert; die Sequenz aus Abschnitt 6 laesst sich
unveraendert uebernehmen (nur Datenbytes + CRC ersetzen).

## 8. Reset in den Bootloader (App -> Bootloader)

Fuer einen reinen PC-Workflow muss die App erst in den Bootloader gebracht
werden. Kanal und Inhalt sind jetzt bestimmt:

### Ablauf
```
PC                                  App (0x08018xxx)
--                                  ----------------
HID-Geraet VID 0x2A8A/PID 0x0010 oeffnen
  -> Enumeration -> USB-Port-Zustand obj[0xa2] = 3
64-Byte HID-OUT-Report             -> Empfangsparser 0x0801D634 (Typ 1)
  00 01 3D 50 05 02 11 03 ...        0x0801D75C: Sequenz/Marke/Laenge ok
                                     -> 0x0801D5C2  -> FIFO A
                                     -> 0x0801D900: Nachrichtenobjekt
                                        obj[+16] = Block+3  (Nutzdaten)
                                        obj[+12] = 2        (Laenge)
                                     -> Modul 0x0801819A/0x080181CA
                                        Matcher 0x08018652
                                       selector[0x11] = Definition 1 (Basis 3)
                                       payload[1] = 0x03 -> Index 4
                                     -> Tabelle 0x08036F40[4] id = 0x0304
                                     -> fnTable[3] = 0x08017378
Gerät startet neu  <--------------  SCB->AIRCR = 0x05FA0004
Gerät als "CEBS Bootloader Mode"    -> Upload nach Abschnitt 6
```

### Der App-HID-Report
* Device-Descriptor `0x08037FC0`: bcdUSB 0x0200, idVendor `0x2A8A`,
  idProduct `0x0010`, bcdDevice `0x4032`.
* Interface `0x08037FA4`: `bInterfaceClass = 0x03` (HID), 2 Endpoints.
* Report-Descriptor: Usage Page `0xFF00`, Usage Min 1 / Max 0x40,
  Logical 0..255, **Report Size 8 x Count 0x40 = 64 Byte**, Input + Output,
  **keine Report-ID**.

### Tool-Aufruf
```
python3 tools/stm_display_fw.py reset                 # Steuerrahmen + Trigger
python3 tools/stm_display_fw.py reset --channel 0x300  # andere Kanal-ID
python3 tools/stm_display_fw.py reset --msg "11 07"    # andere Nutzlast
python3 tools/stm_display_fw.py raw "11 03" --app-frame --sync --listen 1500
```
`reset` oeffnet die App-HID-Schnittstelle, sendet zuerst den Steuerrahmen
Typ `0xFE` (setzt den Zaehler der App auf 0), danach den Trigger-Rahmen mit
Sequenz 0, und wartet, bis `"CEBS Bootloader Mode"` erscheint (Exit-Code 0).
`--legacy-wire len|raw` sendet die frueher vermutete Huelle (nur zum Testen).

### Emulator-Nachweis
`python3 tools/emu.py usbtrigger` faehrt den **echten** USB-Empfangsweg der App
und benutzt dabei ausschliesslich Firmware-Code:

```
1) Typ-0xFE-Rahmen           -> Zaehler 0x20000BAC = 0          OK
2) Trigger-Rahmen            -> Parser 0x0801D634 -> FIFO A +1  OK
3) Port-Task 0x0801D81E      -> obj[+12]=2, obj[+16] = "11 03"  OK
4) Matcher                   -> Index 4, id 0x0304,
                                fn = 0x08017378                 OK
   Dispatcher 0x08018D04     -> Reset-Handler erreicht          OK
```

`python3 tools/emu.py hidtrigger` prueft zusaetzlich die alten, verworfenen
Hüllen-Varianten `len`/`raw` (bleibt als Regressionsschutz erhalten).

`python3 tools/emu.py uploadtool` faehrt den **echten Upload-Pfad** des Tools
(`stm_display_fw.Protocol.upload`) gegen den emulierten Bootloader:

```
Reports gesendet  = 4100        (1x 0x10, 1x 0x37, 1x 0x34, 4096x 0x36, 1x 0x3E)
Flash-Writes      = 4096
Endzeiger         = 0x08040000  (erwartet 0x08040000)
Inhalt identisch  = True
```

Damit sind **beide** Tool-Pfade (Trigger und Flashen) gegen den Emulator
verifiziert — nicht nur das Protokoll, sondern der ausgelieferte Code.

### 8.1 Das App-Transportprotokoll (vollstaendig)

Der App-HID-Report ist im **Normalbetrieb** kein Rohbefehl, sondern ein
gerahmtes Transportformat. Es wurde aus Sender (`0x0801D1DA`, baut den
Rahmen) und Empfaenger (`0x0801D634` Typverteilung, `0x0801D75C` Pruefung)
rueckgewonnen - beide Seiten benutzen **dasselbe** Layout:

```
Byte  Bedeutung
 0    Sequenzzaehler   muss  *(0x20000BAC)  entsprechen, sonst verwirft
                       die App den Rahmen und antwortet mit Typ 0xFF
 1    Rahmentyp
 2    0x3D             feste Marke (nur Typ 1)
 3-4  Kanal-ID         u16 little-endian, nur freigegebene IDs
 5    Nutzlaenge       <= 58
 6..  Nutzdaten        auf 64 Byte mit 0x00 aufgefuellt
```

| Typ | Richtung | Bedeutung | Handler |
|-----|---|---|---|
| `0x00` | rein | bis zu 5 CAN-Frames a 11 Byte | `0x0801D65C` |
| `0x01` | rein | ein Frame: Kanal-ID + Daten | `0x0801D75C` -> `0x0801D5C2` |
| `0x02` | rein | Variante | `0x0801D6E8` |
| `0x03` | rein | Datenkanal (Laenge <= 61) | `0x0801D7A6` -> `0x0801D494` |
| `0xFD` | rein | Steuerung | `0x0801D7F4` |
| `0xFE` | rein | **Zaehler auf 0 setzen** | `0x0801D744` |
| `0xFF` | rein | Steuerung (Antwort auf Fehler) | `0x0801D814` |

**Kanal-IDs** (Flash-Tabelle `0x08037B3A`, geprueft von `0x0801D4E2`;
`0x0801D522` prueft die Teilmenge in `0x08037B3C`):

```
0x0550  0x0552  0x0422  0x0425  0x0101  0x0331  0x0668  0x0300
```

**Weg vom Report zur Nachricht** (alles Firmware-Code):

```
0x0801D634  Typverteilung
0x0801D75C  Prueft Sequenz, Marke 0x3D, Laenge <= 58
0x0801D5C2  baut Block  [id_lo][id_hi][len][daten]
0x0801D4E2  ID-Freigabe -> Push in FIFO A  (*(0x20000BA0), Puffer 64 B)
0x0801D81E  Port-Task; 0x0801D900 holt Block aus FIFO A
            Nachrichtenobjekt 0x2000B814 (*(0x2000092C)):
              obj[+12] = len          (u16)
              obj[+16] = Block+3      -> Nutzdaten
              obj[+2]  = 2
0x0801819A  Objekt registrieren (Queue-Zustand 0x2000092C/0x20000930)
0x080181CA  -> 0x08018160  Nachrichtenauswertung
```

**Der Reset-Trigger** ist damit: Rahmen Typ 1, Sequenz 0, beliebige
freigegebene Kanal-ID, Nutzdaten `11 03`.

Warum das sicher ist: die Nutzdaten, die `0x0801D900` ins Objekt schreibt,
sind **identisch** mit den Bytes, mit denen der Emulator im Szenario
`msgprobe`/`trigger` den Reset-Handler findet (Index 4 -> `fnTable[3]` =
`0x08017378`). Der frueher vermutete Rahmen `[len] 11 03` bzw. `11 03 ...`
konnte nicht funktionieren, weil die Bytes dann an der falschen Stelle liegen
und die Marke `0x3D` fehlt.

### 8.2 Offene Punkte

* Auf echter Hardware ist `reset` mit diesem Rahmen noch **nicht** bestaetigt
  (Stand: Emulator verifiziert, Hardware-Test offen).
* Unbekannt ist, ob die App den Kanal `0x0550` akzeptiert, ohne dass ein
  bestimmter Zustand (NM/Session) vorher gesetzt wurde; `--channel` erlaubt
  das Durchprobieren der 8 freigegebenen IDs.
* Der Sender des 11-Byte-Datensatzes fuer Typ 0 (`0x0801D494`, OTA-Kanal) ist
  nicht weiter untersucht.

## 9. Flash-Ablauf auf echter Hardware (Stand 2026-10-04)

### 9.1 Loeschen (`0x31/0x1FF00`)

* Das Loeschen von 224 KiB (112 Seiten a 2 KiB) dauert **~2,5 s**; der
  Bootloader quittiert erst nach der letzten Seite. Ein 4-s-Wartefenster war
  zu kurz -- das Tool meldete "keine Antwort", obwohl der Bereich danach leer
  war. Deshalb: `ERASE_TIMEOUT_MS = 60000` (Option `--erase-timeout S`) mit
  Fortschrittsausgabe.
* Antwort `71 01 ff 00 <status>`: **`status = 0` = ok, `1` = Fehler**
  (Handler `0x080014D2` ueber `0x0800130C`; im Modus-1-Zweig `0x0800134C`
  wird `r5 == 1` auf `0` und `r5 == 2` auf `1` abgebildet; auf Hardware und im
  Emulator `blupload` bestaetigt).

### 9.2 Schreiben (`0x36`) -- Sequenz und Quittungen

* Nach `0x37` (Sequencer) **und** `0x34` (Adresse) erwartet das Geraet
  **Sequenz 1** (am Geraet gemessen: seq 1 -> Programmfehler `0x72`,
  seq 2/3 -> Sequenzfehler `0x73`).
* `0x37` allein genuegt nicht: `0x36` antwortet dann mit **`0x24`**
  ("Datenmodus" fehlt) -- erst `0x34` setzt das Flag.
* Erfolgreiche `0x36`-Bloecke werden **nicht** einzeln quittiert; nur Fehler
  kommen sofort (`7f 36 73` Sequenz, `7f 36 72` Programmieren), und einmalig
  `0x76`, wenn der Zeiger `0x08040000` erreicht.
* **Ein abgelehnter Block erhoeht die erwartete Sequenz nicht** -- danach
  scheitert jeder weitere Block mit `0x73`. Fehler also immer mit
  Resync (0x37 + 0x34) und erneutem Senden beantworten.

### 9.2.1 DATENSTROM-MODUS -- die eigentliche Ursache aller 0x72-Fehler

Der Bootloader kennt **zwei** Betriebsarten, und der Rahmenaufbau wechselt:

| | Kommando-Modus | Datenstrom-Modus |
|---|---|---|
| Nutzlast | `[cmd][…]` | **nur Daten** (kein Kommando-/Sequenzbyte) |
| Laenge | beliebig (cmd-abhaengig) | = Anzahl zu programmierender Bytes |
| Zieladresse | aus dem Kommando (`0x34`) | Schreibzeiger, laeuft mit |
| Antwort | je Kommando | nur Fehler bzw. `76` am Ende |

Umschaltung: Das **erste erfolgreiche `0x36`** setzt `[0x2000001C] = 1`
(Handler `0x08001614`, `strb r1,[r5]` bei `0x08001682`). Ab dann geht
**jede** Nutzlast an `0x0800168A` statt an den Dispatcher
(`0x08000B32/34`: `cbz r0, Dispatcher`) und wird mit
`f_801998(Zeiger, Laenge, payload)` wortwoertlich programmiert.

Zurueck in den Kommandomodus kommt das Geraet nur, wenn

* der Zeiger **exakt `0x08040000`** erreicht (`0x080016C4` -> Antwort `76 <seq>`), oder
* ein Programmierfehler auftritt (`0x080016AE`: Fehlerantwort `0x72`, Flag = 0).

Das Flag bleibt deshalb so hartnaeckig: geloescht wird es beim Empfang nur,
wenn der **vorherige** Rahmen eine Antwort erzeugt hat -- Merker ist das
TX-Fertig-Flag `[0x20000171]`, das `0x08003AD8` nach `[0x20000247]` spiegelt
und `0x08000ACC` auswertet. Ein `0x36`-Block **antwortet nicht**, also fehlt
der Merker und der Strom laeuft weiter.

**Damit erklaert sich der Hardwarefehler bei exakt `0x080081C0`** (= 8 x 56):
Block 1 lief als Kommando (56 Byte), die Bloecke 2..8 wurden als Datenstrom
mit je **58** Byte Nutzlast (einschliesslich `36 xx`!) programmiert. Der
Geraetezeiger stand dadurch 14 Byte weiter als die Hostrechnung; das Resync
`0x37`+`0x34` setzte ihn auf `0x080081C0` **zurueck** -- also mitten in
beschriebenen Flash. Programmieren kann nur 1 -> 0, die abschliessende
Verifikation der Blob-Routine faellt durch (Status 4) -> Wrapper 3 ->
Fehler `0x72`. **Kein WRP, kein 0xFF-Problem.**

**Richtiges Verfahren** (`Protocol.upload_stream()`, ueber `upload … --region app`
jetzt der Standard):

1. Sitzung (`0x10`) + `0x31/0x10203` (Unlock), Bereich seitenweise loeschen.
2. `0x37` + `0x34` auf den Start (`0x08008000`) -> Erwartung Sequenz 1.
3. **Ein** Kommandorahmen `36 01 <56 Byte>`.
4. Danach 4095 **reine Datenrahmen** a 56 Byte. App-Bereich = `0x38000` Byte =
   exakt `4096 x 56`, der letzte Rahmen endet also genau auf `0x08040000`
   -> Antwort `76` und Kommandomodus ist wieder aktiv.
5. App-CRC (`0x31/0x10202`) pruefen, dann `0x3E 0x80` (Reset).

Wichtig: die 0xFF-Bloecke duerfen **nicht** uebersprungen werden (der Zeiger
muss lueckenlos bis `0x08040000` laufen); 0xFF auf geloeschtem Flash zu
programmieren ist erlaubt (nur 1 -> 0 wird geschrieben). Der Blob lehnt
Adressen `< 0x08007800` ab (`0x080019A6`), der Bootloader-Bereich ist also
grundsaetzlich nicht ueber `0x36` beschreibbar.

**Falle: die Laenge muss GERADE sein.** Die Programm-Routine rechnet die
Laenge in Halbwoertern (`0x0800526E: lsrs r0,r0,#1`) und verifiziert genau
diese Anzahl. Ein einzelnes Byte am Ende wird also **stillschweigend nicht
programmiert** -- und weil die Verifikation dasselbe verkuerzte Fenster
prueft, meldet das Geraet trotzdem Erfolg. Am 2026-10-04 auf Hardware
beobachtet: `36 01 A0` (1 Byte) -> keine Fehlermeldung, aber die
Datensatzseite blieb `ff ff ff ff ff ff`; der Datenstrom wurde trotzdem
aktiviert. `Protocol.cmd_write_block()`/`cmd_write_stream()` lehnen ungerade
Laengen daher mit `ValueError` ab, und `writetest` benutzt einen 2-Byte-Block.

Emulatorbeweis: `python3 tools/emu.py uploadtool` faehrt **beide** Wege -- das
alte Verfahren muss scheitern ("Geraet kommt nicht zurueck", `[0x2000001C]=1`),
das Stromverfahren liefert `Flash == Image` (0 abweichende Bytes), Zeiger
`0x08040000`, App-CRC Status 0 und sauberes `FLASH_SR`.

### 9.3 Upload-Verfahren im Tool -- historisch (`--legacy-blocks`)

> **Ueberholt.** Dieses blockweise Verfahren ist genau das, was am
> Datenstrom-Modus scheitert (siehe 9.2.1). Es bleibt nur fuer
> Vergleichsmessungen im Emulator erhalten (`--legacy-blocks`).

`Protocol.upload()` arbeitet in Blockbuendeln (Standard 8 Bloecke a 56 Byte):

1. `0x37` + `0x34` -- Sequencer und Adresse absolut setzen,
2. Buendel senden,
3. Fehlerrahmen einsammeln (`--settle-ms`, Standard 40 ms),
4. `0x24` (Datenmodus fehlt) -> Sitzung neu aufbauen und weiter,
5. `0x73` (Sequenzfehler) -> **ab dem ersten abgelehnten Block weiter**
   (siehe 9.5), niemals Bloecke wiederholen, die schon geschrieben sind,
6. `0x72` (Programmierfehler) -> **sofortiger Abbruch** mit Hinweis auf
   Power-Cycle (siehe 9.4),
7. bei USB-Abriss (`HIDException`) neu verbinden (ueber
   `Transport.reopen()`), Sitzung neu aufbauen und weiter,
8. `--pace-ms` (Standard 20 ms) Pause je Buendel,
9. Endkontrolle: `0x31/0x10202` -- **erst bei Status 0** wird `0x3E` (Reset)
   ausgeloest; bei Status 1 bleibt das Geraet im Bootloader (erneut flashen,
   dann wird vorher geloescht).

Nach dem Loeschen (und gelegentlich mitten im Schreiben) meldet hidapi einen
Transportfehler (``OSError``/``HIDException``). Das ist **kein Abstecken**: das
Geraet bleibt am Bus, ``dmesg`` bleibt leer. Ursache ist die Unlock-Routine des
Blobs (`+0x2C`), die fuer Flash-Befehle den Systemtakt umschaltet:

* ``RCC_CR &= 0xFEF2FFFF`` -> HSEON, HSEBYP, CSSON und **PLLON** aus,
* ``RCC_CR |= 1`` (HSI an) und ``RCC_CFGR = 0x9F0000`` (SW = HSI),
* danach ``FLASH_KEYR = KEY1/KEY2``.

Der USB-Takt kommt vom PLL (USBPRE) -- also ist das Geraet waehrend und kurz
nach einem Flash-Befehl **stumm**, ohne sich abzumelden. Deshalb:

* ``Transport.recv()`` wiederholt einen fehlgeschlagenen Lesevorgang einmal
  nach 20 ms,
* ``Transport.reopen()`` unterscheidet: Knoten noch da -> nur neu oeffnen
  (Stall), Knoten weg -> auf Neuanmeldung warten,
* ``--settle-ms`` (120 ms) und ``--pace-ms`` (50 ms) halten die Pausen
  gross genug, damit die stumme Phase nicht mit dem naechsten Kommando
  zusammenfaellt,
* jede Sitzung entsperrt den Flash explizit mit ``0x31/0x10203``.

### 9.3.1 Fallstrick: Lese-Timeout 0 blockiert (hidapi-Bindungen)

Die beiden verbreiteten ``hid``-Bindungen behandeln ``read(len, 0)``
**unterschiedlich**:

* neue Bindung (``hid.Device.read(size, timeout)``, ctypes-Variante): ``0``
  geht als ``hid_read_timeout(..., 0)`` raus -> nicht blockierend,
* klassische Bindung (``hid.device.read(max_length, timeout_ms=0)``, z. B. das
  PyPI-Wheel ``hidapi 0.15.0``): ``timeout_ms <= 0`` geht auf **``hid_read()``**
  -> das ist der *blockierende* Aufruf und wartet **unbegrenzt** auf einen
  Report.

Im Datenstrom antwortet das Geraet auf erfolgreiche Rahmen nicht. Ein
``recv(0)``/``poll(0)`` blieb deshalb in der klassischen Bindung genau am
Stromanfang stehen -- direkt nach dem ersten ``-> … | 36 01 …`` kam keine
Ausgabe mehr, obwohl das Geraet weiterlief. Deshalb:

* ``Transport.recv()``/``Transport.poll()`` runden das Timeout ueber
  ``_hid_timeout()`` auf **mindestens 1 ms** auf (und auf ``int``),
* der Drain des ersten ``0x36``-Rahmens (``Protocol.cmd_write_block()``) nutzt
  ``poll()`` statt ``recv()``: ein Lesefehler ist dort normal und darf den
  Handle **nicht** mitten im Strom neu aufbauen.

### 9.4 Latchender Flash-Fehlerzustand -- Mechanismus bewiesen

Wer auf **nicht geloeschten** Flash programmiert (Loeschen unvollstaendig
oder Block doppelt geschrieben), setzt beim STM ein Fehlerbit im `FLASH_SR`.
Danach nimmt der Controller **weder Loeschen noch Programmieren** an, auch
nicht auf leerem, ungeschuetztem Bereich:

* Loeschen meldet **Status 1** (und loescht nichts),
* jeder `0x36`-Block meldet **`7f 36 72`**.

Ursache im Code: der RAM-Blob prueft beim Eintritt `SR` bit 4/bit 2
(`0x080051E0` Erase, `0x0800527A` Program) und bricht dann ab. Die Routine,
die `SR` per W1C (`0x34` = bits 2/4/5) wieder loeschen wuerde, steht erst
**hinter** dieser Pruefung (`0x08005202`) -- sie wird nie erreicht.

**Kein Kommando entfernt das Bit** (getestet: `0x10`, `0x37`, `0x34`,
`0x31/0x10202`, `0x2E`), und ein Software-Reset (`0x3E 0x80`) half auf der
Hardware ebenso wenig wie 90 s Stille. **Nur ein Power-Cycle** (Akku/Display
kurz trennen) setzt `FLASH_SR` zurueck.

Nachgestellt im Emulator: `python3 tools/emu.py blsticky` laeuft mit dem
*echten* Bootloader-Code und dem FLASH-Modell und prueft alle sechs Schritte
(Sollweg, PGERR, Erase -> Status 1, Schreiben -> 0x72, kein Kommando loescht
das Bit, Power-Cycle hilft) -- 13/13 Checks gruen.

### 9.6 Flash-Sonde vor dem Schreiben (Datensatzseite 0x08007800)

Der Erase-Befehl meldet auch dann Erfolg, wenn das Flash-Interface gesperrt
ist (er prueft nur BSY). Der erste Programmierversuch trifft dann **belegten**
Flash, setzt ein Fehlerbit und laesst danach gar nichts mehr zu (9.4).

Deshalb prueft ``Protocol.flash_canary()`` den kompletten Pfad
Unlock/Erase/Programm/Verify **vor** dem App-Schreiben -- auf der einzigen
Seite, die beschreibbar *und* wieder lesbar ist: dem Geraeterekord bei
``0x08007800`` (ausserhalb der App-CRC).

* schreiben: ``0x2E`` mit Magic ``0xF15A``, Payload-Laenge exakt 10
  (Jahr/Monat/Tag + 4 Datenbytes), ACK ``6e f1 5a``,
* zuruecklesen: ``0x22``/``0xF15B`` -> 6 Byte, Vergleich mit dem Geschriebenen.

Die Sonde laeuft dreimal: nach dem Sitzungsaufbau, nach dem Loeschen und nach
jedem Sitzungs-Neuaufbau (z. B. nach einem Takt-Stall). Schlaegt sie fehl,
wird **nichts** im Applikationsbereich geschrieben -- es genuegt ein
Power-Cycle, das Geraet bleibt unversehrt. Im Emulator geprueft durch
``python3 tools/emu.py uploadtool`` (dort laeuft die Sonde ueber den echten
Code mit).

### 9.5 Regel: jeden Halbwort nur EINMAL programmieren

Weil ein zweiter Schreibzugriff auf dieselbe Stelle das Fehlerbit setzt, darf
ein Wiederholungsversuch **niemals** schon geschriebene Bloecke erneut senden.
Nutze die Fehlerrahmen als Zaehler: bei einem Sequenzfehler (`0x73`) wurde der
erste abgelehnte Block und alles danach **nicht** geschrieben, alles davor
schon. Also gilt `geschrieben = gesendet - Fehlerrahmen`, und der
Wiederaufsetzpunkt ist die Adresse des ersten abgelehnten Blocks. Deshalb
wurde die fruehere Variante "Buendel komplett wiederholen" und auch ein
zweiter Durchgang ohne Loeschen (`--passes`) wieder entfernt.

End-to-End im Emulator: `python3 tools/emu.py uploadtool` fahrt den echten
`Protocol.upload()`-Pfad (Loeschen, Buendel mit Resync, CRC-Endkontrolle,
Reset) gegen den echten Bootloader-Code -- Flash == Image, Zeiger korrekt,
CRC-Status 0, keine Fehler, `FLASH_SR` sauber.

Empfohlener Ablauf bei diesem Bild:

1. Stromversorgung trennen, kurz warten, wieder anschliessen,
2. `python3 tools/stm_display_fw.py info` (Bootloader muss erscheinen),
3. `python3 tools/stm_display_fw.py flash data/stm32f105_bms_control.bin --region app`
   -- Erase, Buendel mit Wiederholungen, CRC-Endkontrolle, Reset.

### 9.7 Nach dem Flashen: nur ein Power-Cycle startet die Applikation [V]

**Zwei Gruende, warum nach dem Upload nichts passiert:**

**1. `0x3E 0x80` macht von sich aus gar keinen Reset.** Der Rahmen ist korrekt
(Laenge 2, Arg `0x80`, Handler `0x08001884` akzeptiert ihn), aber er *armiert
nur einen Zaehler*: `5000` nach `0x20000042` (`0x080018A6/AC`). Verringert wird
er im Rahmen-Empfangspfad -- `0x08000BD4`..`0x08000C04` (Tail jeder
Rahmenverarbeitung) ruft `0x0800190A`, das `[0x20000042]` um **eins je
empfangenem USB-Rahmen** dekrementiert (Voraussetzung: `[0x20000040] == 1`,
das setzt der Flash-Pfad). Der `0x3E`-Rahmen selbst zaehlt dabei mit, der
Zaehler steht danach also auf `4999`. Es ist **kein Zeitgeber**: das offizielle
Host-Tool hat den Reset offenbar „leergepollt". Unser Werkzeug sendet nach
`0x3E` keinen einzigen Rahmen mehr -- der Zaehler bleibt bei 4999 stehen, es
gibt **keinen Reset** und damit auch keine USB-Neuanmeldung in `dmesg`.

**2. Und selbst dieser Reset wuerde die Applikation nicht starten.** Er ist ein
Software-Reset (`AIRCR`/`SYSRESETREQ`) und setzt `RCC_CSR.SFTRSTF`; genau dann
bleibt die Firmware im Bootloader (siehe Bootablauf oben):

| Reset-Ursache | `0x080019F0` | Ergebnis |
|---|---|---|
| **nur `SFTRSTF`** (bit 28: Software-Reset, auch `0x3E`/`AIRCR`) | 0 | `0x08001AAA` = **Bootloader** (Update-Modus) |
| alles andere (Pin, Power-On, IWDG, WWDG, Low-Power) | 1 | `0x08001AC4` -> `0x08001A3C` = **Sprung in die Applikation** (`MSP` aus `0x08008000`, Reset-Vektor aus `0x08008004`) |

Beide Wege verlangen zusaetzlich eine **gueltige App-CRC** (`0x08001A02`,
sonst bleibt es beim Bootloader). Genau das ist auch der Grund, warum
`NVIC_SystemReset` in der App *immer* im Bootloader landet (Abschnitt 8).

**Folge fuer das Werkzeug:** es gibt **keinen Befehl**, der die Applikation
startet. Nach dem Flashen muss das Geraet kurz stromlos gemacht werden
(Stecker ziehen und wieder anstecken = Pin-Reset); dann springt der Bootloader
in die neue Applikation. Das Werkzeug sagt das nach dem Upload und wartet 20 s
auf die Enumeration der App (`APP_START_HINT` in `stm_display_fw.py`).

Emulatorbeweise mit dem **echten** Bootloader-Code:

```
python3 tools/emu.py finishtimer
[fin] [ok  ] 0x3E 0x80 armt den Zaehler (5000, minus den eigenen Rahmen)   Zaehler=4999
[fin] [ok  ] Zaehler sinkt um 1 je empfangenem Rahmen (nach 100 Rahmen)   Zaehler=4899
[fin] [ok  ] Reset erst nach ~4999 weiteren Rahmen   nach 4999 Rahmen: AIRCR=0x05fa0004
[fin] [ok  ] Reset ist ein Software-Reset (SYSRESETREQ, fuehrt in den BL)   AIRCR=0x05fa0004
[fin] Ohne weitere Rahmen nach 0x3E gibt es also gar keinen Reset.

python3 tools/emu.py bootdecision
[boot] [ok  ] PINRSTF (Stecker/Strom)  -> Zweig App-Start
[boot] [ok  ] PORRSTF (Power-On)       -> Zweig App-Start
[boot] [ok  ] SFTRSTF (SW-Reset, 0x3E) -> BOOTLOADER bleibt aktiv
[boot] [ok  ] SFTRSTF + CRC falsch     -> BOOTLOADER bleibt aktiv
[boot] [ok  ] PINRSTF + CRC falsch     -> BOOTLOADER bleibt aktiv
[boot] Es gibt keinen Befehl, der die Applikation startet -- ein Software-Reset
[boot] (auch 0x3E 0x80) laeuft per Firmware-Logik wieder in den Bootloader.
```

Damit ist die frueher dokumentierte Annahme ("`0x3E 0x80` ... wodurch die App
startet") widerlegt.

## 10. CAN-Bruecke der App (HID <-> CAN) [V]

Die App ist nicht nur Nachrichtenempfaenger, sondern **Bruecke zum CAN-Bus**:
Rahmen aus dem HID-Transport werden gesendet, empfangene CAN-Frames zum Host
gemeldet. Verifiziert end-to-end im Emulator mit dem ausgelieferten Tool:
`python3 tools/emu.py canbridge`.
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

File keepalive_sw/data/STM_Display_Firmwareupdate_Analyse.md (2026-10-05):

# STM "Display"-Firmware (STM32F105) – Firmware-Update-Mechanismus

Quelle: `stm32f105_conti.hex` (Cortex-M3, 256 KB Flash @ `0x08000000`).
Disassembly: `stm32f105_conti.dis` (siehe `make_disassembly.sh`).

## Ergebnis

**Ja, es gibt einen Firmware-Update-Mechanismus.** Der Dump enthält **zwei
unabhängig gelinkte Programme** (je eigene Vektor-Tabelle + C-Runtime):

| Region | Adresse | Rolle | USB-Identität |
|---|---|---|---|
| Bootloader | `0x08000000`–`0x08007FFF` (32 KB) | IAP-Updater, USB-HID | `CEBS Bootloader Mode` |
| Applikation | `0x08008000`–`0x0803FFFF` | eBike-Display | `Continental eBike System` |

CRC32-Absicherung: `CRC32(0x08008000..0x0803FFFB) = 0x561FEB04`,
gespeichert **Big-Endian** am Flash-Ende `0x0803FFFC`.
Nachgerechnet mit dem STM32-Hardware-CRC (Poly `0x4C11DB7`, Init `0xFFFFFFFF`)
→ **stimmt exakt überein**.
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

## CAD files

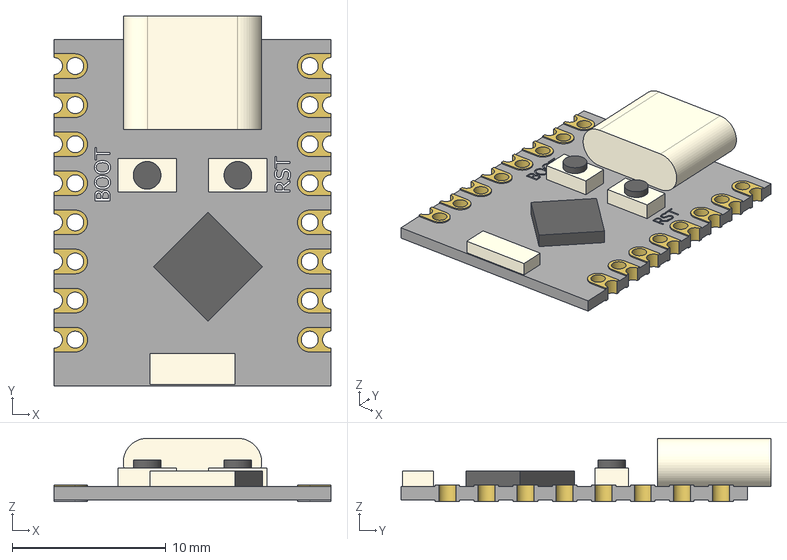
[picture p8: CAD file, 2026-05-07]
hw/KiCad_ESP32-C3-SuperMini/ESP32-C3-SuperMini.stp
18.0 x 24.0 x 4.12 mm

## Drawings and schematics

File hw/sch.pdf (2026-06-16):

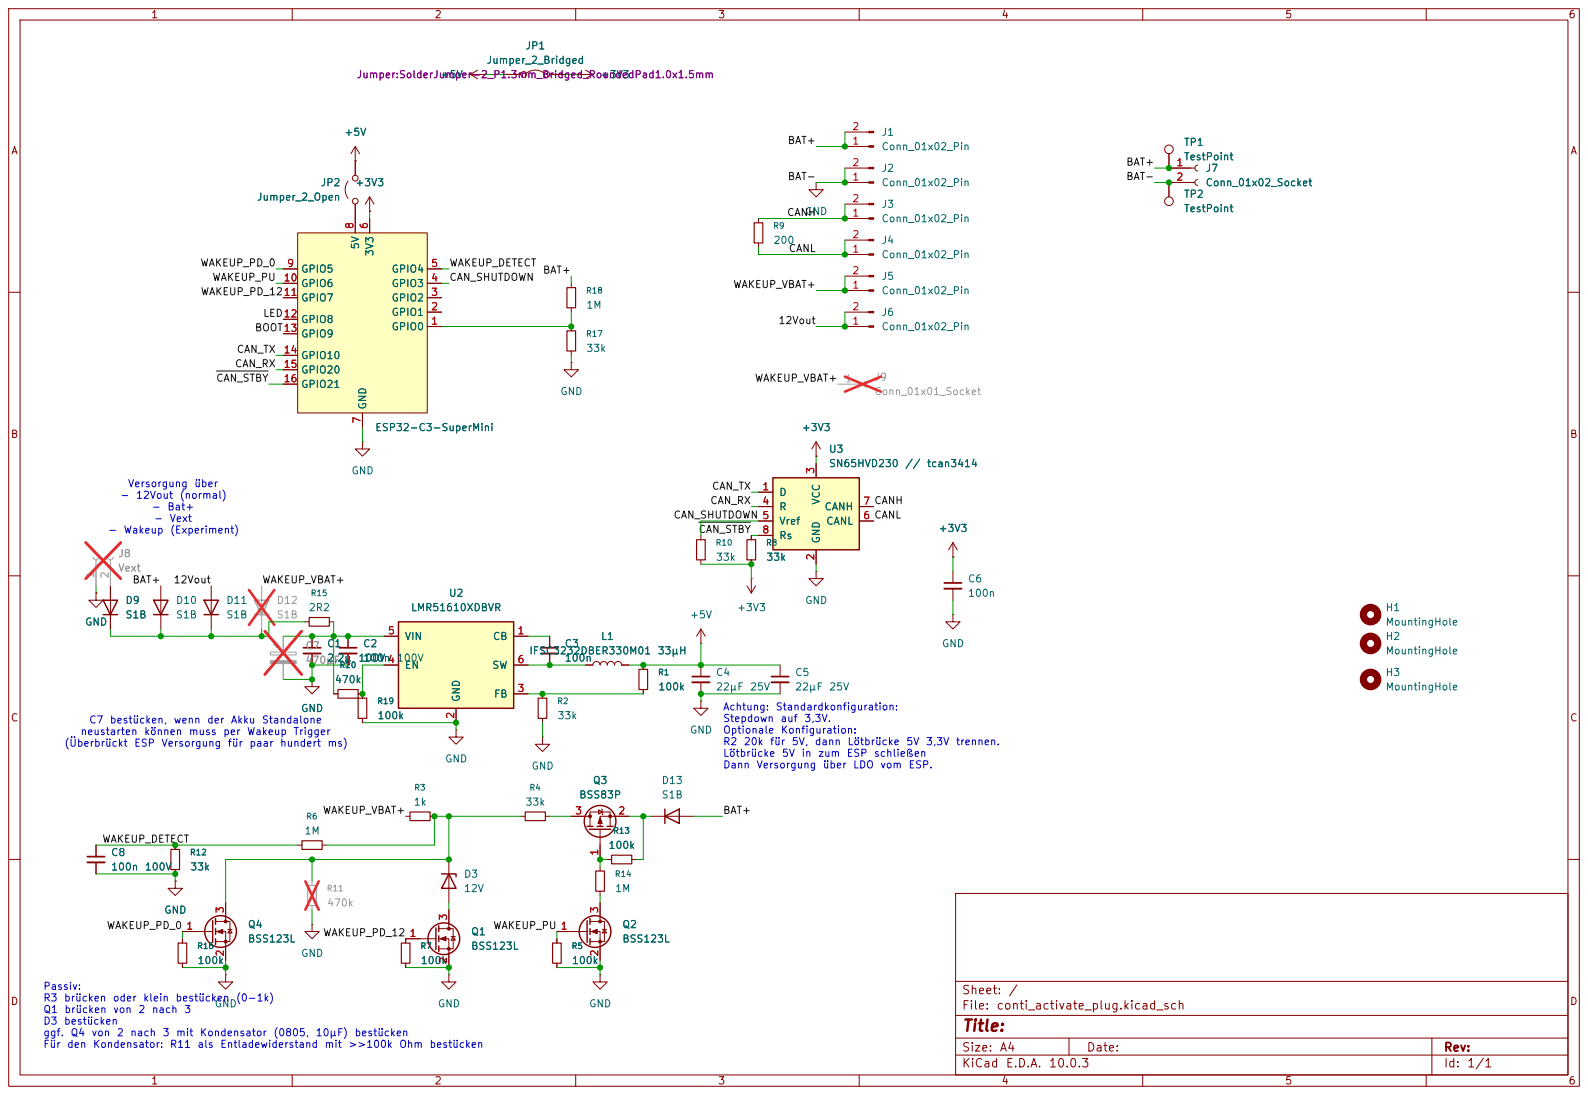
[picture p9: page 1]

6 GND
- Vext - Wakeup (Experiment) Passiv: R3 brücken oder klein bestücken (0-1k) Q1 brücken von 2 nach 3 D3 bestücken

Versorgung über - 12Vout (normal) - Bat+

Optionale Konfiguration: R2 20k für 5V, dann Lötbrücke 5V 3,3V trennen. Lötbrücke 5V in zum ESP schließen Dann Versorgung über LDO vom ESP. C7

Für den Kondensator: R11 als Entladewiderstand mit >>100k Ohm bestücken C7 bestücken, wenn der Akku Standalone neustarten können muss per Wakeup Trigger (Überbrückt ESP Versorgung für paar hundert ms)

ggf. Q4 von 2 nach 3 mit Kondensator (0805, 10µF) bestücken

Size: A4 | Rev:
KiCad E.D.A. 10.0.3 | Id: 1/1

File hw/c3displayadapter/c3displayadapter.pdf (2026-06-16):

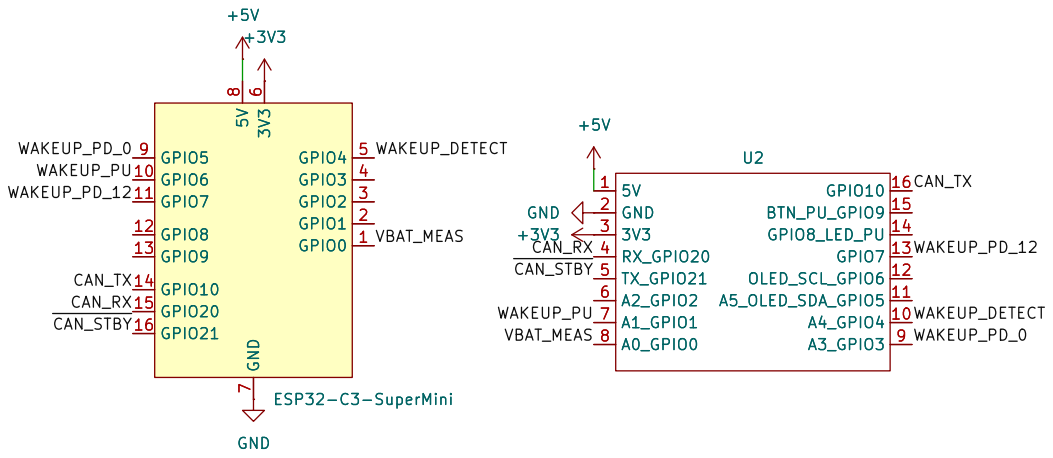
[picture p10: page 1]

Size: A4 | Rev:
KiCad E.D.A. 10.0.3 | Id: 1/1

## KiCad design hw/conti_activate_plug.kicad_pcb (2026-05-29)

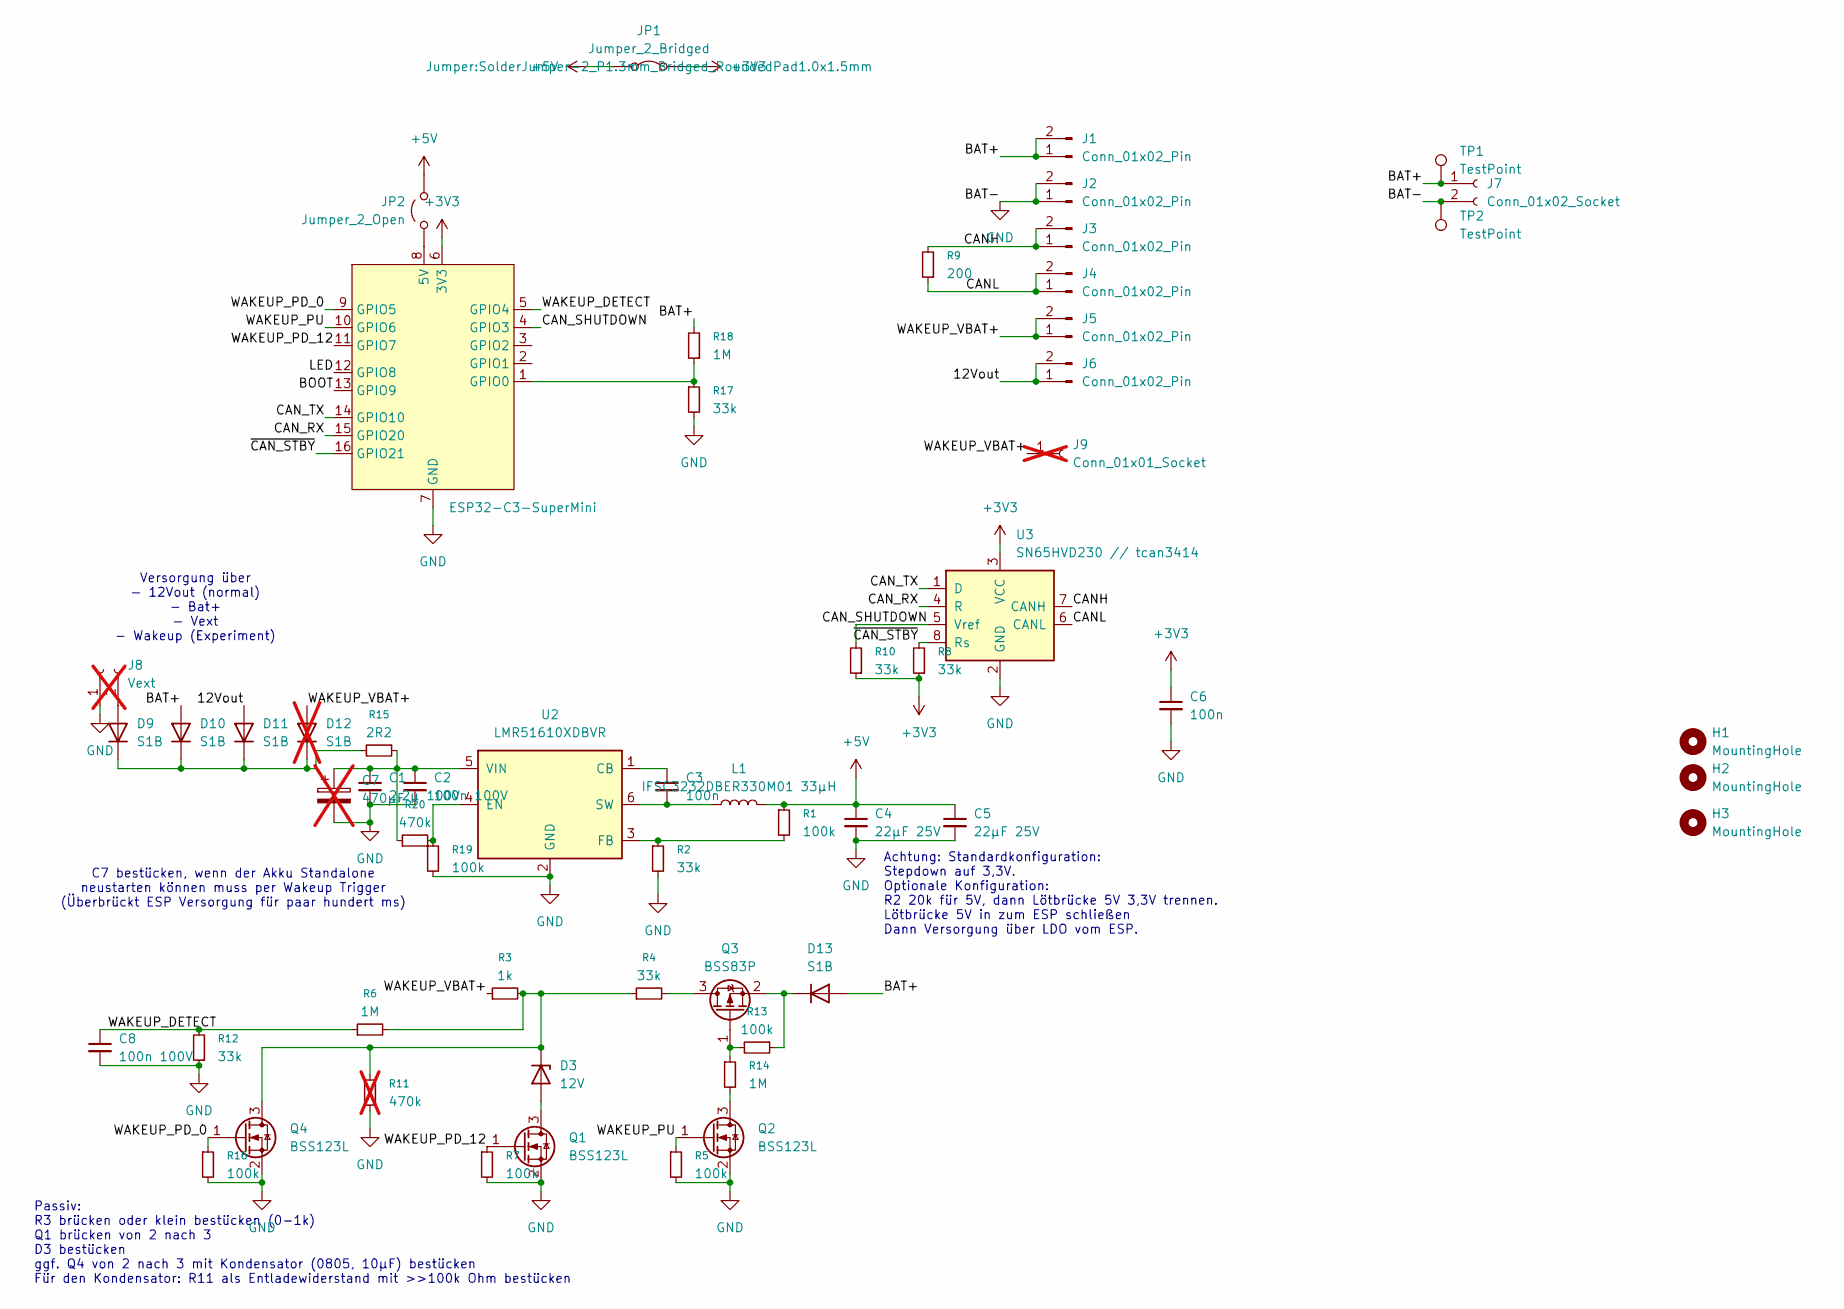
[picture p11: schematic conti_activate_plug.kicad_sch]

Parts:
C1: 2,2µ 100V; C_1206_3216Metric; LCSC C13585
C2, C8: 100n 100V; C_0603_1608Metric; LCSC C14663
C3, C6: 100n; C_0603_1608Metric; LCSC C14663
C4, C5: 22µF 25V; C_0805_2012Metric; LCSC C45783
C7: 470µF; CP_Radial_Tantal_D8.0mm_P5.00mm; not fitted
D3: 12V; D_SOD-123F; LCSC C22395569
D9, D10, D11, D13: S1B; D_SOD-123F; LCSC C64898
D12: S1B; D_SOD-123F; LCSC C64898; not fitted
H1, H2, H3: MountingHole; MountingHole_3.2mm_M3
J1, J2, J3, J4, J5, J6: Conn_01x02_Pin; 1x02_P5.08mm
J7: Conn_01x02_Socket; TerminalBlock_CUI_TB007-508-02_1x02_P5.08mm_Horizontal
J8: Vext; PinHeader_1x02_P2.54mm_Vertical; not fitted
J9: Conn_01x01_Socket; PinHeader_1x01_P2.54mm_Vertical; not fitted
JP1: Jumper_2_Bridged; SolderJumper-2_P1.3mm_Bridged_RoundedPad1.0x1.5mm
JP2: Jumper_2_Open; SolderJumper-2_P1.3mm_Open_RoundedPad1.0x1.5mm
L1: IFSC3232DBER330M01 33µH; L_Chilisin_BWVS00808040; LCSC C354641
Q1, Q2, Q4: BSS123L; SOT-23; LCSC C7420338
Q3: BSS83P; SOT-23; LCSC C7420340
R1, R5, R7, R13, R16, R19: 100k; R_0603_1608Metric; LCSC C25803
R2, R4, R8, R10, R12, R17: 33k; R_0603_1608Metric; LCSC C4216
R3: 1k; R_0603_1608Metric; LCSC C21190
R6, R14, R18: 1M; R_0603_1608Metric; LCSC C22935
R9: 200; R_0603_1608Metric; LCSC C8218
R11: 470k; R_0603_1608Metric; LCSC C23178; not fitted
R15: 2R2; R_0603_1608Metric; LCSC C22939
R20: 470k; R_0603_1608Metric; LCSC C23178
TP1, TP2: TestPoint; TestPoint_Loop_D3.80mm_Drill2.8mm
U1: ESP32-C3-SuperMini
U2: LMR51610XDBVR; SOT-23-6; LCSC C20539658
U3: SN65HVD230 // tcan3414; SOIC-8_3.9x4.9mm_P1.27mm; LCSC C12084

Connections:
+3V3: C6.1, JP1.2 (B), R8.1, R10.1, U1.6 (3V3), U3.3 (VCC)
+5V: C4.1, C5.1, JP1.1 (A), JP2.1 (A), L1.2, R1.1
/12Vout: D11.2 (A), J6.1, J6.2
/BAT+: D10.2 (A), D13.2 (A), J1.1, J1.2, J7.1, R18.2, TP1.1 (1_1)
/BOOT: U1.13 (GPIO9)
/CANH: J3.1, J3.2, R9.2, U3.7 (CANH)
/CANL: J4.1, J4.2, R9.1, U3.6 (CANL)
/CAN_RX: U1.15 (GPIO20), U3.4 (R)
/CAN_SHUTDOWN: R10.2, U1.4 (GPIO3), U3.5 (Vref)
/CAN_TX: U1.14 (GPIO10), U3.1 (D)
/LED: U1.12 (GPIO8)
/WAKEUP_DETECT: C8.1, R6.1, R12.2, U1.5 (GPIO4)
/WAKEUP_PD_0: Q4.1 (G), R16.1, U1.9 (GPIO5)
/WAKEUP_PD_12: Q1.1 (G), R7.1, U1.11 (GPIO7)
/WAKEUP_PU: Q2.1 (G), R5.1, U1.10 (GPIO6)
/WAKEUP_VBAT+: D12.2 (A), J5.1, J5.2, J9.1 (Pin_1_1), R3.1
/~CAN_STBY: R8.2, U1.16 (GPIO21), U3.8 (Rs)
GND: C1.2, C2.2, C4.2, C5.2, C6.2, C7.2, C8.2, J2.1, J2.2, J7.2, J8.1, Q1.2 (S), Q2.2 (S), Q4.2 (S), R2.2, R5.2, R7.2, R11.1, R12.1, R16.2, R17.2, R19.2, TP2.1 (1_1), U1.7 (GND), U2.2 (GND), U3.2 (GND)
unnamed: D3.2 (A), Q1.3 (D)
unnamed: D3.1 (K), Q4.3 (D), R3.2, R4.1, R6.2, R11.2
unnamed: D9.2 (A), J8.2
unnamed: D9.1 (K), D10.1 (K), D11.1 (K), D12.1 (K), R15.2
unnamed: D13.1 (K), Q3.2 (S), R13.1
unnamed: JP2.2 (B), U1.8 (5V)
unnamed: Q2.3 (D), R14.2
unnamed: Q3.3 (D), R4.2
unnamed: Q3.1 (G), R13.2, R14.1
unnamed: R17.1, R18.1, U1.1 (GPIO0)
unnamed: C3.1, U2.1 (CB)
unnamed: R19.1, R20.2, U2.4 (EN)
unnamed: R1.2, R2.1, U2.3 (FB)
unnamed: C3.2, L1.1, U2.6 (SW)
unnamed: C1.1, C2.1, C7.1, R15.1, R20.1, U2.5 (VIN)

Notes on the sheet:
C7 bestücken, wenn der Akku Standalone neustarten können muss per Wakeup Trigger (Überbrückt ESP Versorgung für paar hundert ms)
Passiv: R3 brücken oder klein bestücken (0-1k) Q1 brücken von 2 nach 3 D3 bestücken ggf. Q4 von 2 nach 3 mit Kondensator (0805, 10µF) bestücken Für den Kondensator: R11 als Entladewiderstand mit >>100k Ohm bestücken
Achtung: Standardkonfiguration: Stepdown auf 3,3V. Optionale Konfiguration: R2 20k für 5V, dann Lötbrücke 5V 3,3V trennen. Lötbrücke 5V in zum ESP schließen Dann Versorgung über LDO vom ESP.
Versorgung über - 12Vout (normal) - Bat+ - Vext - Wakeup (Experiment)

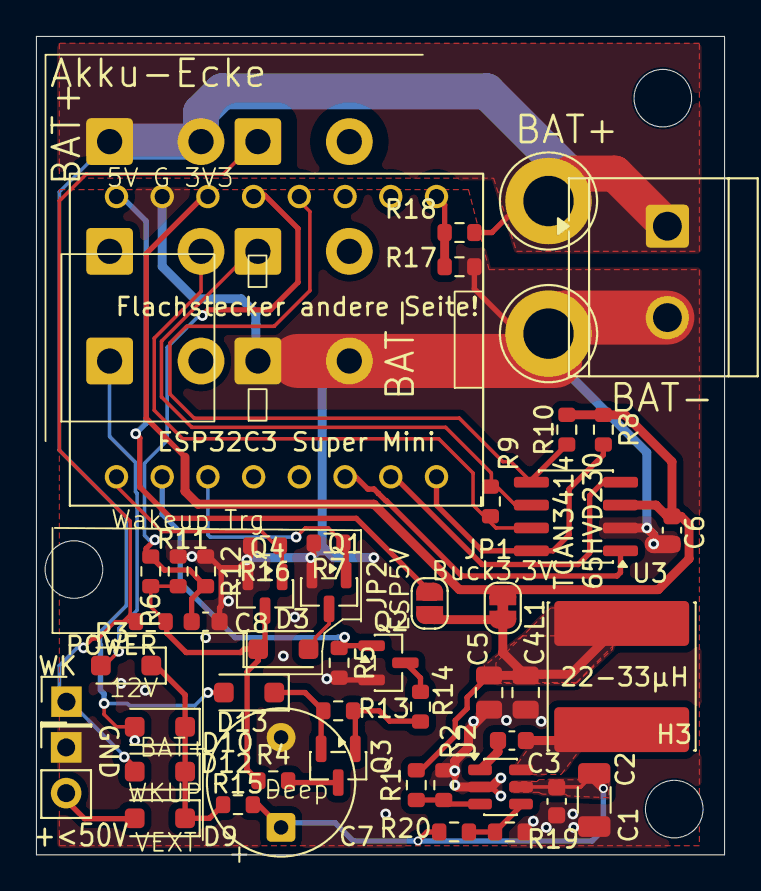
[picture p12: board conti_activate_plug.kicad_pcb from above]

Board: 2 copper layers, 38.2 x 45.5 mm, 58 parts (0 on the bottom side), 31 nets.

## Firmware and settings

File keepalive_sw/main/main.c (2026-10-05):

#include "gpio_ctrl.h"
#include "adc_meas.h"
#include "can_bus.h"
#include "wake_trigger.h"
#include "wifi_ap.h"
#include "webserver.h"
#include <esp_ota_ops.h>
#include <esp_system.h>
#include <nvs_flash.h>
#include <sys/param.h>
#include "oled_display.h"
#include "freertos/FreeRTOS.h"
#include "freertos/task.h"

/**
 * @brief Append the last cached analog vehicle inputs to the CAN log at a
 *        fixed rate so the "12 V half-on" and "35-42 V on" states can be
 *        correlated with the CAN traffic in the /canlog viewer.
 *        The ADC itself is sampled by adc_meas' background task.
 *        Payload: wakeup-detect, Vbat, CAN-shutdown (all millivolts, LE).
 */
static void telemetry_task(void *arg)
{
    while (1) {
        uint16_t w = (uint16_t)(adc_get_wakeup_detect_voltage() * 1000.0f);
        uint16_t v = (uint16_t)(adc_get_vbat_voltage() * 1000.0f);
        uint16_t s = (uint16_t)(adc_get_can_shutdown_voltage() * 1000.0f);
        uint8_t  d[6] = {
            (uint8_t)(w & 0xFF), (uint8_t)(w >> 8),
            (uint8_t)(v & 0xFF), (uint8_t)(v >> 8),
            (uint8_t)(s & 0xFF), (uint8_t)(s >> 8),
        };
        can_log_append(CAN_LOG_ID_ANALOG, sizeof(d), d);
        vTaskDelay(pdMS_TO_TICKS(250));
    }
}

void app_main(void)
{
    gpio_ctrl_init();     /* Wakeup outputs, LED, boot button         */
    adc_meas_init();      /* WAKEUP_DETECT + CAN_SHUTDOWN ADC channels */
    wifi_ap_init();       /* NVS, netif, WiFi AP (192.168.4.1)        */
    can_bus_init();       /* TWAI 250 kbit/s, receive task, timer      */
    webserver_init();     /* HTTP server with status page and API      */
    wake_trigger_init();  /* Battery wake trigger state machine        */
    oled_display_init();  /* OLED display (OLED variant only; no-op otherwise) */
    xTaskCreate(telemetry_task, "can_telemetry", 3072, NULL, 2, NULL);

    gpio_set_led(true); /* LED on: system running */

    /* Mark current app as valid */
	const esp_partition_t *partition = esp_ota_get_running_partition();
	printf("Currently running partition: %s\r\n", partition->label);

	esp_ota_img_states_t ota_state;
	if (esp_ota_get_state_partition(partition, &ota_state) == ESP_OK) {
		if (ota_state == ESP_OTA_IMG_PENDING_VERIFY) {
			esp_ota_mark_app_valid_cancel_rollback();
		}
	}

    /* All work runs in tasks/timers; keep the main task alive */
    while (1) {
        vTaskDelay(pdMS_TO_TICKS(10000));
    }
}

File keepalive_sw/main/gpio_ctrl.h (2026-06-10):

#pragma once
#include <stdbool.h>
#include "sdkconfig.h"

/* -----------------------------------------------------------------------
 * Pin definitions – variant-specific
 *
 * SuperMini:  GPIO5 = WakeupPD0V,   GPIO6 = WakeupPU_BAT
 * OLED:       GPIO3 = WakeupPD0V,   GPIO1 = WakeupPU_BAT
 *             (GPIO5/6 used for OLED SDA/SCL)
 * --------------------------------------------------------------------- */
#ifdef CONFIG_HW_VARIANT_OLED
#define PIN_WAKEUP_PD0V    3  /**< Wakeup Pulldown 0V  (OLED variant: GPIO3) */
#define PIN_WAKEUP_PU_BAT  1  /**< Wakeup Pullup BAT+  (OLED variant: GPIO1) */
#else
#define PIN_WAKEUP_PD0V    5  /**< Wakeup Pulldown 0V  (SuperMini: GPIO5)    */
#define PIN_WAKEUP_PU_BAT  6  /**< Wakeup Pullup BAT+  (SuperMini: GPIO6)    */
#endif

#define PIN_WAKEUP_PD12V   7  /**< Wakeup Pulldown 12V, output, init low */
#define PIN_LED            8  /**< Status LED, active low                 */
#define PIN_BOOT           9  /**< Boot button, active low, ext. pullup   */

/**
 * @brief Initialize all GPIO pins.
 *        Wakeup outputs are driven low, LED is off (high), boot pin is input.
 */
void gpio_ctrl_init(void);

/** @brief Set Wakeup Pulldown 0V (GPIO5). */
void gpio_set_wakeup_pd0v(bool active);

/** @brief Set Wakeup Pullup BAT+ (GPIO6). */
void gpio_set_wakeup_pu_bat(bool active);

/** @brief Set Wakeup Pulldown 12V (GPIO7). */
void gpio_set_wakeup_pd12v(bool active);

/** @brief Control status LED (on = GPIO low). */
void gpio_set_led(bool on);

/** @brief Current output state of Wakeup PD 0V. */
bool gpio_get_wakeup_pd0v(void);

/** @brief Current output state of Wakeup PU BAT+. */
bool gpio_get_wakeup_pu_bat(void);

/** @brief Current output state of Wakeup PD 12V. */
bool gpio_get_wakeup_pd12v(void);

/** @brief Read boot button (true = pressed / GPIO low). */
bool gpio_get_boot_button(void);

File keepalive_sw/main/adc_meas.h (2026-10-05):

#pragma once
#include "sdkconfig.h"

/**
 * ADC pin definitions.
 *
 * VBAT_MEAS     (GPIO0): direct battery voltage, Vbat = Vmeas * 1033 / 33
 * WAKEUP_DETECT (GPIO4): voltage divider,        Vact = Vmeas * 1033 / 33
 * CAN_SHUTDOWN  (GPIO3): diagnostic pin voltage  (SuperMini only; on OLED
 *                        variant GPIO3 is a digital output)
 */
#define PIN_VBAT_MEAS      0  /**< GPIO0: battery voltage (both variants)   */
#define PIN_WAKEUP_DETECT  4  /**< GPIO4: wakeup detect (both variants)      */
#ifndef CONFIG_HW_VARIANT_OLED
#define PIN_CAN_SHUTDOWN   3  /**< GPIO3: CAN shutdown (SuperMini only)      */
#endif

/**
 * @brief Initialize ADC unit and calibration and start the sampling task.
 *        GPIO0 (Vbat) and GPIO4 (WakeupDetect) on both variants.
 *        GPIO3 (CAN_Shutdown) only on SuperMini.
 *
 * All conversions are performed by a single background task which caches the
 * results; the adc_get_*() accessors below only read that cache and never
 * touch the ADC hardware, so they are cheap and safe to call from any task.
 */
void adc_meas_init(void);

/**
 * @brief Latest cached battery voltage at GPIO0 (Vbat = Vmeas * 1033/33).
 * @return Actual battery voltage [V].
 */
float adc_get_vbat_voltage(void);

/**
 * @brief Latest cached Wakeup-Detect voltage (GPIO4, divider 1033/33).
 * @return Actual signal voltage [V].
 */
float adc_get_wakeup_detect_voltage(void);

int adc_get_vbat_percent(void);

#ifdef CONFIG_HW_VARIANT_OLED
/** CAN_SHUTDOWN ADC not available on OLED variant (GPIO3 is digital output). */
static inline float adc_get_can_shutdown_voltage(void) { return 0.0f; }
#else
/**
 * @brief Latest cached voltage at CAN_SHUTDOWN pin (GPIO3, SuperMini only).
 * @return Pin voltage [V].
 */
float adc_get_can_shutdown_voltage(void);
#endif

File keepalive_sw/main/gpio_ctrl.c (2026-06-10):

#include "gpio_ctrl.h"
#include "driver/gpio.h"

static bool s_pd0v   = false;
static bool s_pu_bat = false;
static bool s_pd12v  = false;

void gpio_ctrl_init(void)
{
    /* Outputs: wakeup signals + LED */
    gpio_config_t out_cfg = {
        .pin_bit_mask = (1ULL << PIN_WAKEUP_PD0V)  |
                        (1ULL << PIN_WAKEUP_PU_BAT) |
                        (1ULL << PIN_WAKEUP_PD12V)  |
                        (1ULL << PIN_LED),
        .mode         = GPIO_MODE_OUTPUT,
        .pull_up_en   = GPIO_PULLUP_DISABLE,
        .pull_down_en = GPIO_PULLDOWN_DISABLE,
        .intr_type    = GPIO_INTR_DISABLE,
    };
    gpio_config(&out_cfg);

    /* Input: boot button — external pullup, no internal pull */
    gpio_config_t in_cfg = {
        .pin_bit_mask = (1ULL << PIN_BOOT),
        .mode         = GPIO_MODE_INPUT,
        .pull_up_en   = GPIO_PULLUP_DISABLE,
        .pull_down_en = GPIO_PULLDOWN_DISABLE,
        .intr_type    = GPIO_INTR_DISABLE,
    };
    gpio_config(&in_cfg);

    /* Initial output levels */
    gpio_set_level(PIN_WAKEUP_PD0V,  0);
    gpio_set_level(PIN_WAKEUP_PU_BAT, 0);
    gpio_set_level(PIN_WAKEUP_PD12V, 0);
    gpio_set_level(PIN_LED, 1);  /* LED off (active low) */
}

void gpio_set_wakeup_pd0v(bool active)
{
    s_pd0v = active;
    gpio_set_level(PIN_WAKEUP_PD0V, active ? 1 : 0);
}

void gpio_set_wakeup_pu_bat(bool active)
{
    s_pu_bat = active;
    gpio_set_level(PIN_WAKEUP_PU_BAT, active ? 1 : 0);
}

void gpio_set_wakeup_pd12v(bool active)
{
    s_pd12v = active;
    gpio_set_level(PIN_WAKEUP_PD12V, active ? 1 : 0);
}

void gpio_set_led(bool on)
{
    gpio_set_level(PIN_LED, on ? 0 : 1);  /* active low */
}

bool gpio_get_wakeup_pd0v(void)  { return s_pd0v;   }
bool gpio_get_wakeup_pu_bat(void) { return s_pu_bat; }
bool gpio_get_wakeup_pd12v(void) { return s_pd12v;  }

bool gpio_get_boot_button(void)
{
    return gpio_get_level(PIN_BOOT) == 0;  /* active low */
}

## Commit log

2026-04-21 Initial hw
    [conti_activate_plug.kicad_pcb, conti_activate_plug.kicad_sch]
2026-04-21 Ordnerstruktur, PDF
    [conti_activate_plug.kicad_pcb, conti_activate_plug.kicad_sch]
2026-04-22 Vext, CAN Terminierung, Mounting-Hole
    [conti_activate_plug.kicad_pcb, conti_activate_plug.kicad_sch]
2026-04-23 Stepdown redesigned, TCAN3414, S1B
    [conti_activate_plug.kicad_pcb, conti_activate_plug.kicad_sch]
2026-04-24 paar Komponenten herausgesucht
    [conti_activate_plug.kicad_sch]
2026-05-08 forgot hw/sch
    [conti_activate_plug.kicad_pcb, conti_activate_plug.kicad_sch]
2026-06-16 display adapter
    [c3displayadapter.kicad_pcb, c3displayadapter.kicad_sch]
2026-10-05 Dist-Paket reproduzierbar bauen (tools/build_dist.sh)
    Die nur im ignorierten dist/ vorhandenen Dateien (patch.sh, flash.sh,
    requirements.txt, README.md, install-udev.sh) liegen jetzt als Quellen in
    tools/ und werden von tools/build_dist.sh zusammen mit tools/* und data/*
    zu dist/cebs_display_bms_patch/ (+ .zip) zusammengesetzt.
2026-10-05 keepalive_sw: Threading-/Stack-Fixes, Web-OTA-Werkzeuge, beide HW-Varianten
    Review-Fixes (main/):
    - ADC: eine Sample-Task statt konkurrierender adc_oneshot_read()-Aufrufe.
    Der interne Try-Lock lieferte bei Ueberlappung ESP_ERR_TIMEOUT, was still
    als 0 mV gemittelt wurde. Accessoren lesen jetzt einen Cache.
    - CAN: periodisches Senden blockiert nicht mehr im esp_timer-Callback
    (Timeout 0, best-effort).
    - Stacks: wake_trigger/oled 2048 -> 3072, httpd 6144 -> 8192.
    - OTA: esp_ota_abort() auf Fehlerpfaden, NULL-Check der Update-Partition.
    - wifi_ap: Sendeleistung 8 -> 16 (0,25-dBm-Schritte).
    Werkzeuge (tools/):
    - build_esp32.sh baut SuperMini und OLED (per-Variante sdkconfig, Projekt-
    sd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
    [adc_meas.c, adc_meas.h, can_bus.c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]
2026-10-05 keepalive_sw: weitere BMS-Werte auf der Web-Statusseite dekodieren
    Entsprechend der Feldzuordnung aus tools/cebs_ble.py werden jetzt zusaetzlich
    dekodiert und im Web-UI angezeigt:
    - SOH (0x404 Byte 5)
    - RemainingCapacity (0x405 Bytes 0-1)
    - FullChargeCapacity (0x405 Bytes 2-3)
    can_battery_data_t um soh_percent/remaining_mah/full_mah erweitert. 0x405
    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
2026-10-05 keepalive_sw: CAN-Log in groesseren Bloecken seltener abholen
    Bei schlechtem WLAN (absichtlich niedrige Sendeleistung, SuperMini-Antenne)
    hat der 500-ms-Refresh mit 256er-Bloecken Requests ueberlappt und ist dem
    CAN-Aufkommen hinterhergelaufen.
    - Server: CAN_LOG_MAX_CHUNK 256 -> 1024
    - Viewer: CHUNK 1024, Ruhe-Intervall 3000 ms; selbstschedulendes poll()
    statt setInterval, damit sich Requests nicht mehr ueberlappen. Bei
    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
2026-10-05 keepalive_sw: Hinweis zur WiFi-Sendeleistung im SuperMini ergaenzen
    Der Kommentar haelt fest, dass die niedrige Sendeleistung (16) im SuperMini
    absichtlich ist (Antennenproblem) und nicht weiter erhoeht werden darf.
2026-10-05 keepalive_sw: CAN-Log-Antwort kompakter und gebuendelt senden
    Die 1024-Eintraege-Antwort war ~80 kB und dauerte 500-800 ms. Statt jeden
    Eintrag einzeln als JSON-Objekt (mit wiederholten Schluesselnamen) in einem
    eigenen HTTP-Chunk zu senden, wird jetzt:
    - jeder Eintrag als kompaktes Array [seq,t,id,dlc,tx,"hex"] ausgegeben
    (etwa halbe Nutzlast),
    - die Antwort in ~2-KB-Bloecken gesendet (wenige grosse statt ~1000 kleine
    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
2026-10-05 keepalive_sw: CAN-Log-Puffer an die TCP-MSS anpassen und auf den Heap legen
    Der 2-KB-Ausgabepuffer war unpassend:
    - MTU 1500 minus IP/TCP-Header ergibt hier CONFIG_LWIP_TCP_MSS=1440; 2048
    Byte erzeugen pro Flush ein volles plus ein Teilsegment. Jetzt 1408 Byte
    (MSS minus Reserve fuer die Chunked-Kodierung), damit ein Flush in genau
    ein TCP-Segment passt.
    - 2 KB auf dem httpd-Stack sind unnoetig; der Puffer kommt jetzt vom Heap
    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
2026-10-07 Android-App: Akku-Status per BLE anzeigen
    Einfache Android-App (Compose), die beim Start automatisch nach dem
    CEBS-Display scannt und die bereits dekodierte 20-Byte-BMS-Charakteristik
    0x0a01 uebersichtlich anzeigt: Ladezustand gross und farbig, dazu Spannung,
    Strom, Leistung, Rest-/Vollkapazitaet, SOH und die Rohbytes.
    * Scan ueber den Namen 'CEBS' (BLE-Adresse ist eine Zufallsadresse)
    * Notify bevorzugt, zusaetzlich Poll als Rueckfall
    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
2026-10-07 Akku-Telemetrie: Durchschnittsstrom nutzen, Restdauer schaetzen
    Das BMS schickt zwei Stroeme: 0x404 den schnell nachgefuehrten und 0x406
    einen traegen Durchschnitt. Beide stecken in derselben BLE-Charakteristik
    0x0a01 (Byte 1-2 und 15-16).
    * Firmware-Analyse: der periodische USART-Nachrichtenbau (0x0801f5d8,
    Nachricht 1 = 20 Byte) liest die Slots 0x200009D0 (0x404), 0x200009C8
    (0x405) und 0x200009B8 (0x406); die Slot-Tabelle liegt bei 0x8036C80.
    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
2026-10-07 Android-App: BLE-Verbindung im Hintergrund freigeben
    Das CEBS-Display nimmt nur eine BLE-Zentrale an und sendet dann keine Werbung
    mehr - war die App im Hintergrund, kam kein anderes Geraet mehr heran.
    * MainActivity: onStart() verbindet, onStop() gibt die Verbindung frei.
    * BatteryViewModel.disconnect() als Gegenstueck zu connect().
    * BleBatteryClient.stop() beendet jetzt auch den laufenden Scan (stopScan)
    und bricht den Scan-Watchdog ab; der Watchdog wird in cancelPending()
    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
2026-10-07 Android-App: Restdauer unter einer Minute als "< 1 min"
    * formatDuration() ins Modell verschoben (model/DurationFormat.kt) und mit
    Unit-Tests abgedeckt: Minuten unter einer Stunde, "X h Y min" darueber,
    Tage ab 100 h, "< 1 min" statt "0 min".
    * Statt "0 min" bei sehr kurzer Restzeit nun "< 1 min".
    Nebenbei wird die Verbindung jetzt beim Wegschalten der App freigegeben
    (onStop), die Anzeige bleibt in der Vordergrundpruefung unveraendert:
    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
